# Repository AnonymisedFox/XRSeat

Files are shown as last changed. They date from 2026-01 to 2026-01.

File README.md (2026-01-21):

# XRSeat prototype 

This repository contains **all the parts, files, and components required for the fabrication and assembly of the XRSeat prototype**.
Every element has been included to ensure a complete understanding of the structure, the interactions between parts, and the overall system behavior.

## Introduction: what is XRSeat?
XRSeat is a system we built to facilitate the creation of multimodal experiences in Extended Reality (XR). 
It is a chair device providing lighting, spatialized audio, vibro-tactile feedback and wind sensations. We submitted a scientific paper to the IMX 2026 conference with more details about this research prototype.

Teaser_v2

To start, we suggest to have a look at the Technical_Drawings_Prototype pdf to have a global view of the chair and its components.
You then then have a look at the list of Required_Hardware, before digging into the design files in the CAD and Step_Files folder. 
Happy exploration!

## Content of this repo
The current repo, anonymised for the submission of the paper, contains:
* Mechanical and structural parts
* Assembly elements
* Design and reference files
* Prototype-specific components

Chaise_XR_v1b

## File Formats

All design files are **also provided in native SolidWorks format**, ensuring full parametric access, editability, and compatibility with SolidWorks-based workflows.

## Known issues
Currently, the POÄNG chair chair model is **not** provided in STEP format.
This results in:
* limited parametric editing,
* constraints when integrating the model into certain CAD software,
* the need for adaptation or conversion if structural modifications are required.

## Final note

Aside from this specific issue, **all other prototype elements are present and usable** in their current format.

---

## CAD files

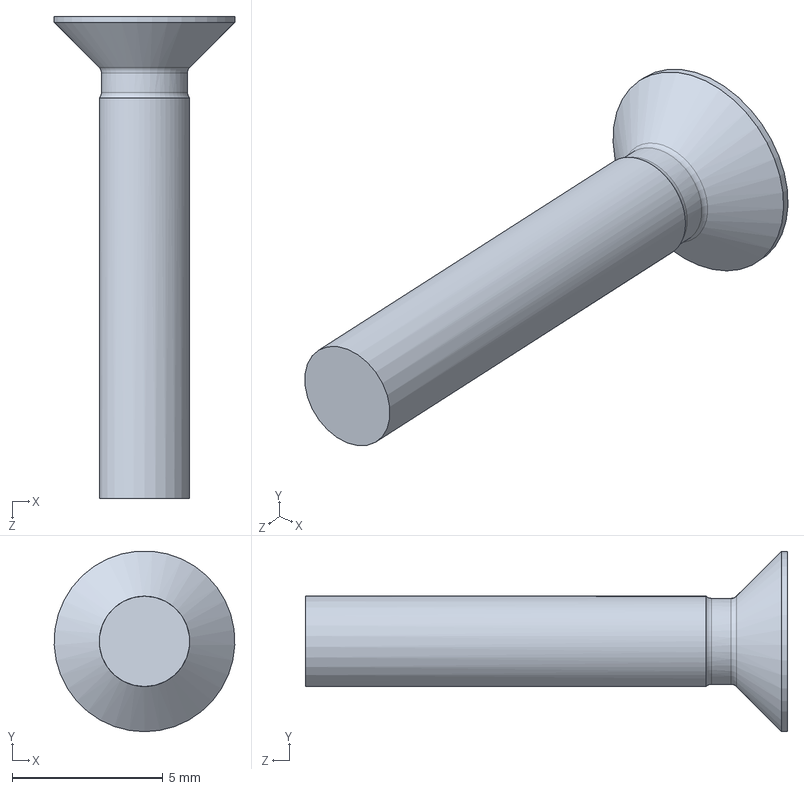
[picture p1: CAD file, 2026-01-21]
CAD/Solidworks/ARMSET_PART/vis_uni_5933_m3x16-a2_0.SLDPRT
5.99 x 5.99 x 16.0 mm

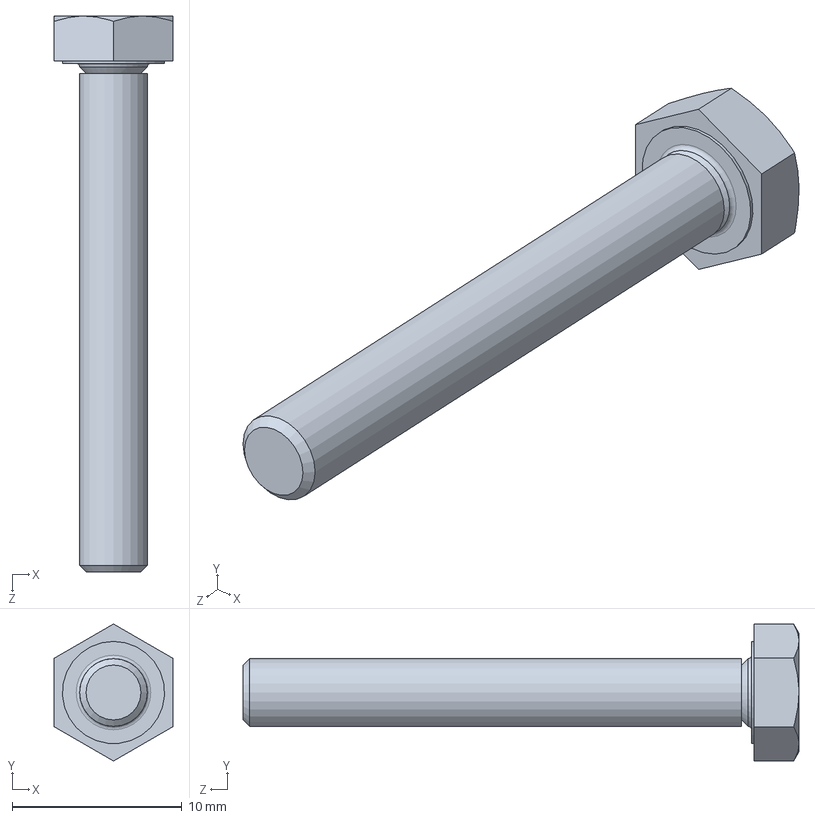
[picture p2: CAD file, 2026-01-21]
CAD/Solidworks/BACK_PART/din_en_24017_m4x30.SLDPRT
7.00 x 8.08 x 32.8 mm

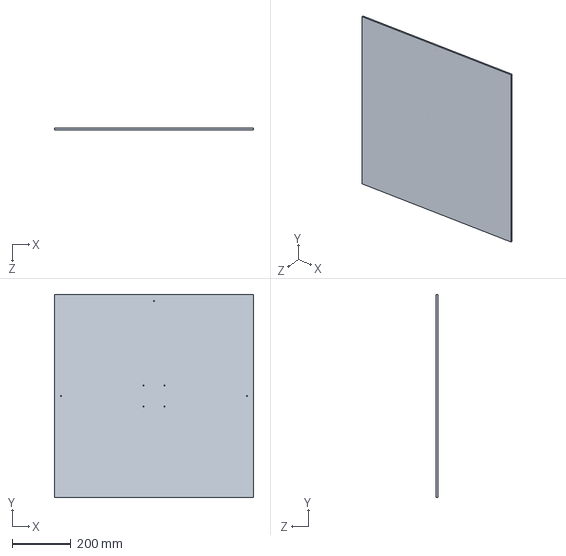
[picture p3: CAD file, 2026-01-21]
CAD/Solidworks/GROUND_PART/FOOT-PLATE.SLDPRT
680.0 x 694.0 x 6.00 mm

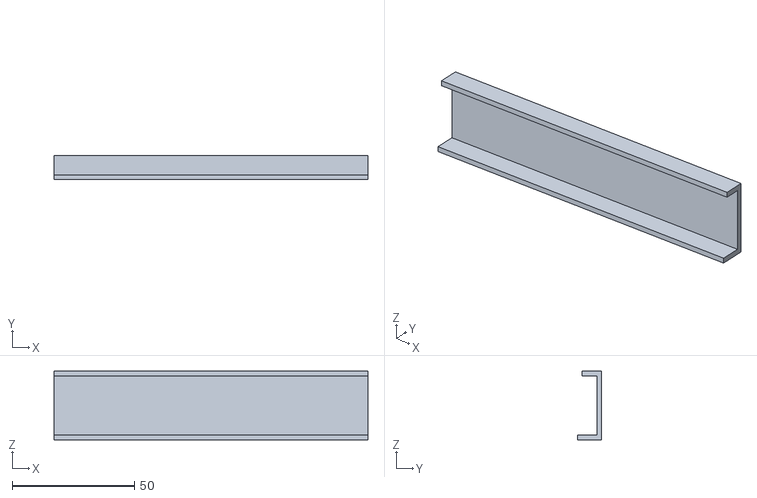
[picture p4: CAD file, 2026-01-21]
CAD/Solidworks/HEAD_PART/LEFT-EAR-Support_LED_P1.STL
128.2 x 10.0 x 28.0

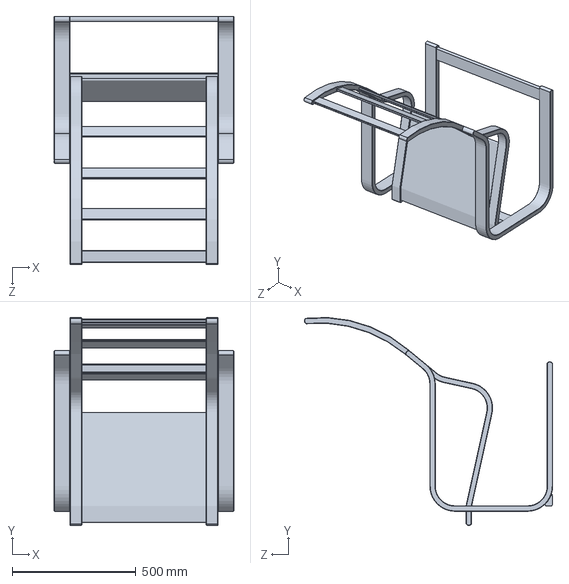
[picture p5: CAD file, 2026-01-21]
CAD/Solidworks/IKEA/POANG-CHAIR.SLDPRT
723.9 x 838.7 x 1001.3 mm

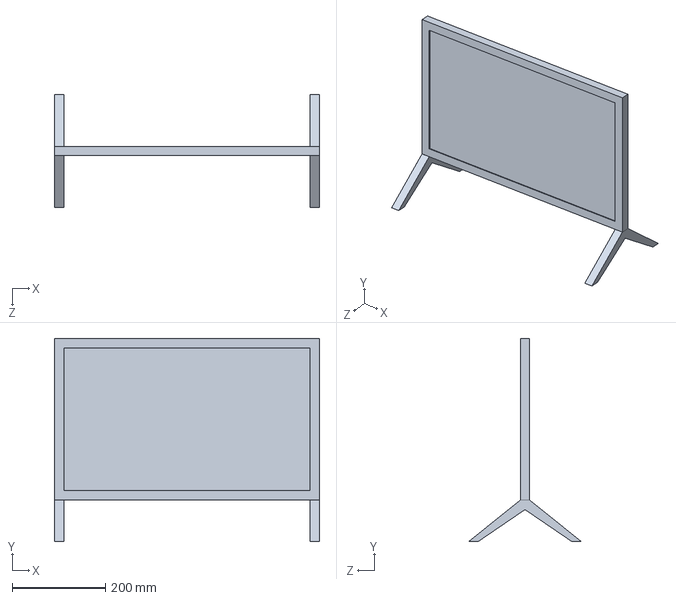
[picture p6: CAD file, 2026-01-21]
CAD/Solidworks/PROJECTION_PART/ILLUMETRY-SCREEN.SLDPRT
568.0 x 435.2 x 241.3 mm

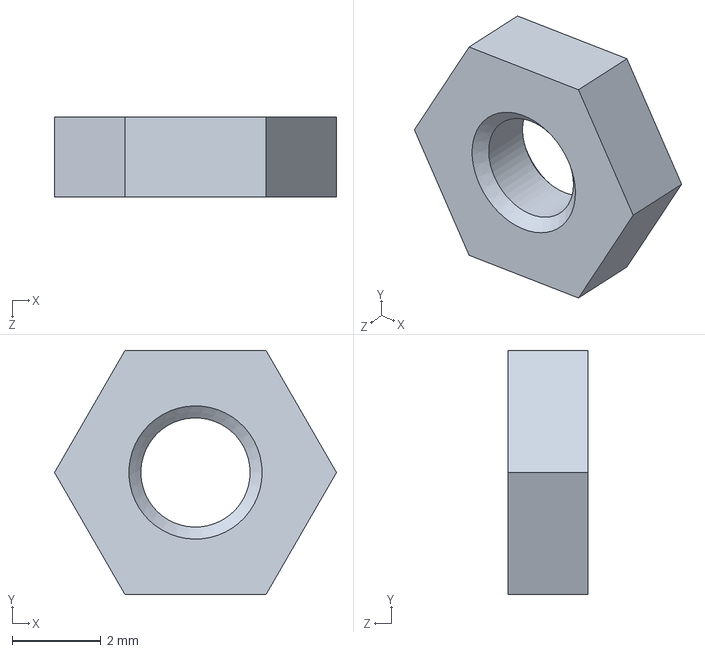
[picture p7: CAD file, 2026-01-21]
CAD/Step_Files/SubComponents/ecrou_iso_4036_m3.STEP
6.35 x 5.50 x 1.80 mm

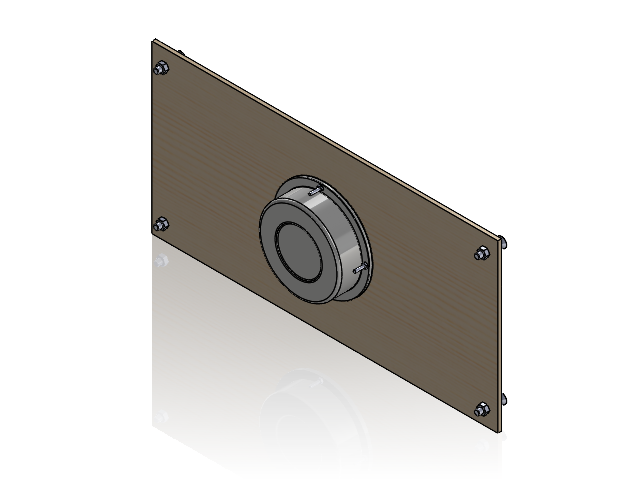
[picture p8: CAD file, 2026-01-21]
CAD/Solidworks/BACK_PART/BACK-PART.SLDASM
BACK-PLATE
BSX 130 WP metal body.stp
Dämpfung.stp
din_en_24017_m4x30 x 4
ecrou_din934_m4-6 x 4
ecrou_din934_m8-10 x 4
vis_uni_5933_m8x40-10_9_0 x 4

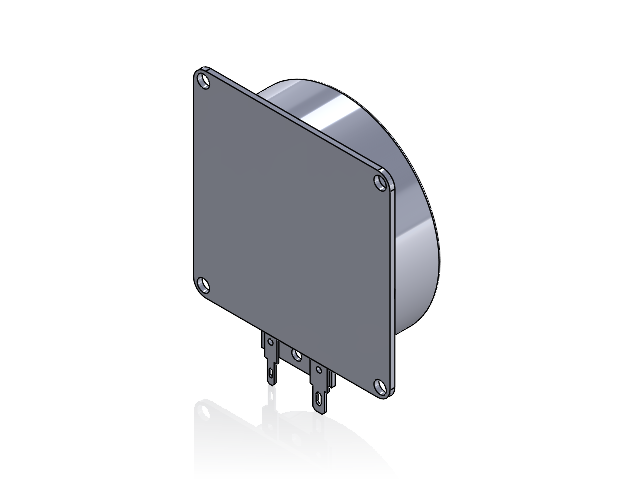
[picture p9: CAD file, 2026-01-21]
CAD/Solidworks/GROUND_PART/EX 80 S.SLDASM
Fiche_Visaton_EX_80_S
Visaton_EX_80_S

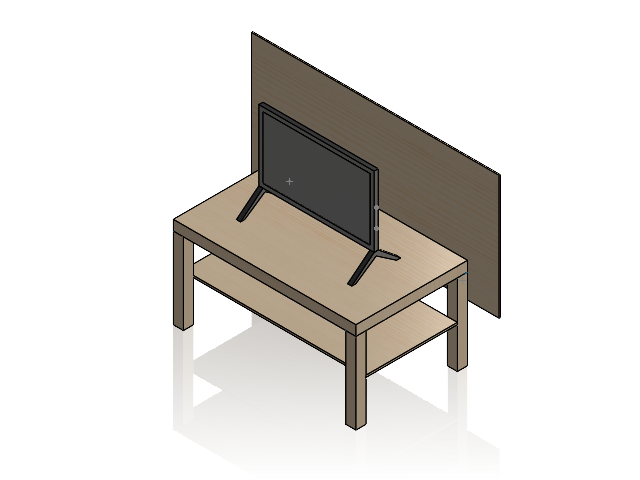
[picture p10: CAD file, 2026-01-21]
CAD/Solidworks/PROJECTION_PART/PROJECTION-PART.SLDASM
ILLUMETRY-SCREEN
LACK_TABLE
PROJECTION_BACK

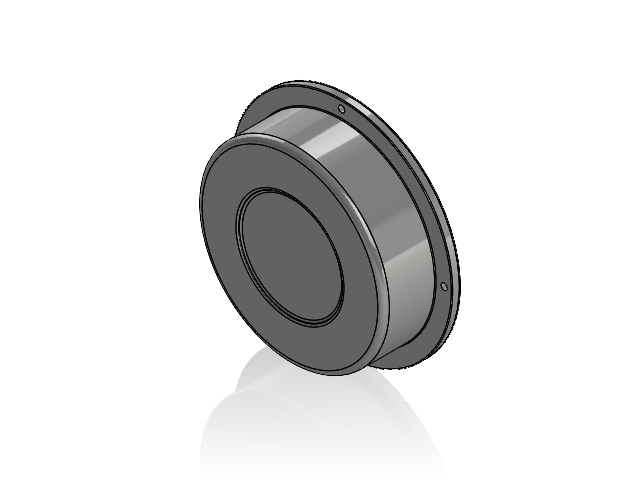
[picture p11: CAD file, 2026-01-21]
CAD/Solidworks/BACK_PART/VISATON BSX 130 WP 150908.SLDASM
BSX 130 WP metal body.stp
Dämpfung.stp

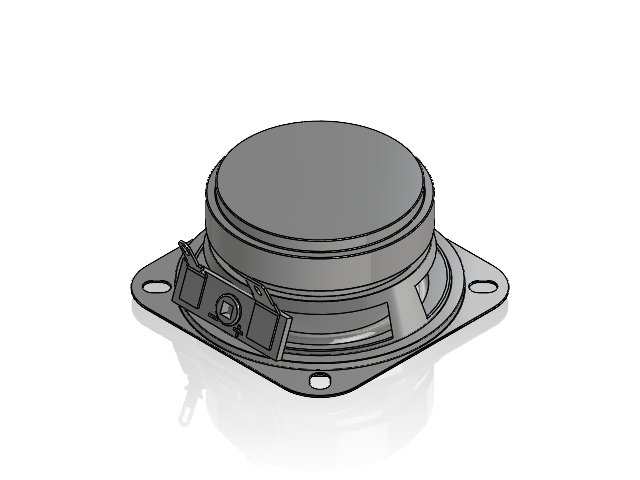
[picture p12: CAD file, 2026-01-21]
CAD/Solidworks/HEAD_PART/VISATON FR 58 170905.SLDASM
FR 58 Korb.stp
FR 58 Membran und Sicke.stp
FR 58 Gummidichtring.stp
FR 58 Magnet.stp
_Terminalplatte 29 x 9,2 x 1,6.stp
_Terminal 2.8-0.5 (135°) 2.stp
_Terminal 5.2-0.5 (135°).stp

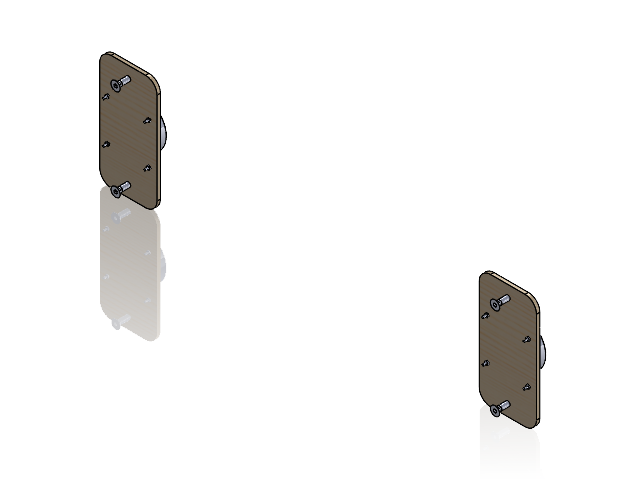
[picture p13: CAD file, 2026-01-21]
CAD/Solidworks/ARMSET_PART/ARMSET-PART.SLDASM
ARMSET-PLATE x 2
EX 80 S x 2
ecrou_iso_4036_m3 x 8
vis_uni_5933_m3x16-a2_0 x 8
ecrou_din934_m8-10 x 4
vis_uni_5933_m8x40-10_9_0 x 4

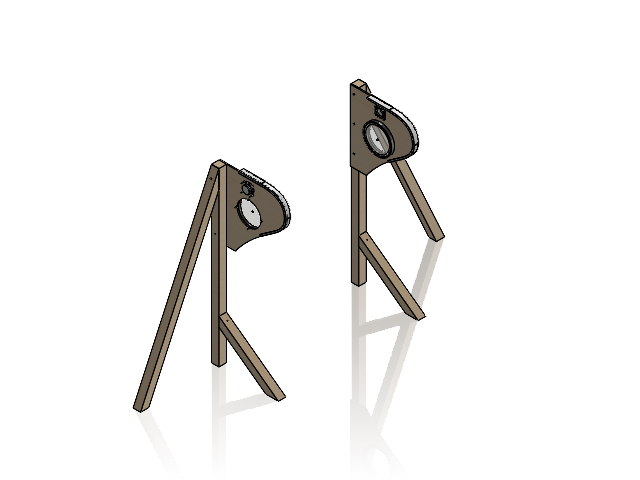
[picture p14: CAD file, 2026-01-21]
CAD/Solidworks/HEAD_PART/HEAD-PART.SLDASM
EAR x 2
WOODEN_BATTEN-1 x 2
WOODEN_BATTEN-2 x 2
WOODEN_BATTEN-3 x 2
screw_gb_t_951_3_5x40 x 10
Synjet_Plexi_TB x 2
Synjet_Support_TB x 2
FR 58 Korb.stp x 2
FR 58 Membran und Sicke.stp x 2
FR 58 Gummidichtring.stp x 2
FR 58 Magnet.stp x 2
_Terminalplatte 29 x 9,2 x 1,6.stp x 2
_Terminal 2.8-0.5 (135°) 2.stp x 2
_Terminal 5.2-0.5 (135°).stp x 2
ecrou_iso_4036_m3 x 16
vis_iso_4017-m3x30-10_9 x 16
EAR-Support_LED_P1 x 2
EAR-Support_LED_P2 x 2

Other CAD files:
CAD/Step_Files/MainStepFile.STEP
CAD/Step_Files/SubComponents/SCENT_ASSEMBLY.STEP
CAD/Step_Files/SubComponents/ARM_WOOD_ASSEMBLY.STEP
CAD/Solidworks/260120-PROTYPE.SLDASM
CAD/Solidworks/ARMSET_PART/ARMSET-PLATE.SLDPRT
CAD/Solidworks/ARMSET_PART/EX 80 S.SLDPRT
CAD/Solidworks/ARMSET_PART/ecrou_din934_m8-10.SLDPRT
CAD/Solidworks/ARMSET_PART/ecrou_iso_4036_m3.SLDPRT
CAD/Solidworks/ARMSET_PART/vis_uni_5933_m8x40-10_9_0.SLDPRT
CAD/Solidworks/BACK_PART/BACK-PLATE.SLDPRT
CAD/Solidworks/BACK_PART/ecrou_din934_m4-6.SLDPRT
CAD/Solidworks/BACK_PART/ecrou_din934_m8-10.SLDPRT
CAD/Solidworks/BACK_PART/vis_uni_5933_m8x40-10_9_0.SLDPRT
CAD/Solidworks/GROUND.SLDPRT
CAD/Solidworks/GROUND_PART/EX 80 S.SLDPRT
CAD/Solidworks/GROUND_PART/Fiche_Visaton_EX_80_S.SLDPRT
CAD/Solidworks/GROUND_PART/Visaton_EX_80_S.SLDPRT
CAD/Solidworks/GROUND_PART/WOODEN_BATTEN-44X44_L271.SLDPRT
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

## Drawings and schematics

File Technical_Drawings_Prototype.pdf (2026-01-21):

sauf indications contraires, unités en mm

NOM | SIGNATURE | DATE | REFERENCE: PROTYPE 13/03/2025

AUTEUR

VERIF. | | | | | ECHELLE:1:20
PROPRIETARY AND CONFIDENTIAL THE INFORMATION CONTAINED IN THIS DRAWING IS THE SOLE PROPERTY OF IMMERSION SAS. ANY REPRODUCTION IN PART OR AS A WHOLE WITHOUT THE WRITTEN PERMISSION OF IMMERSION SAS IS PROHIBITED. | | VERSION: 1.0

NE PAS CHANGER
L'ECHELLE

PAR: | LE:

sauf indications contraires, unités en mm

NOM | SIGNATURE | DATE | REFERENCE: ARMSET-PART 13/03/2025

AUTEUR

VERIF. | | | | | ECHELLE:1:5

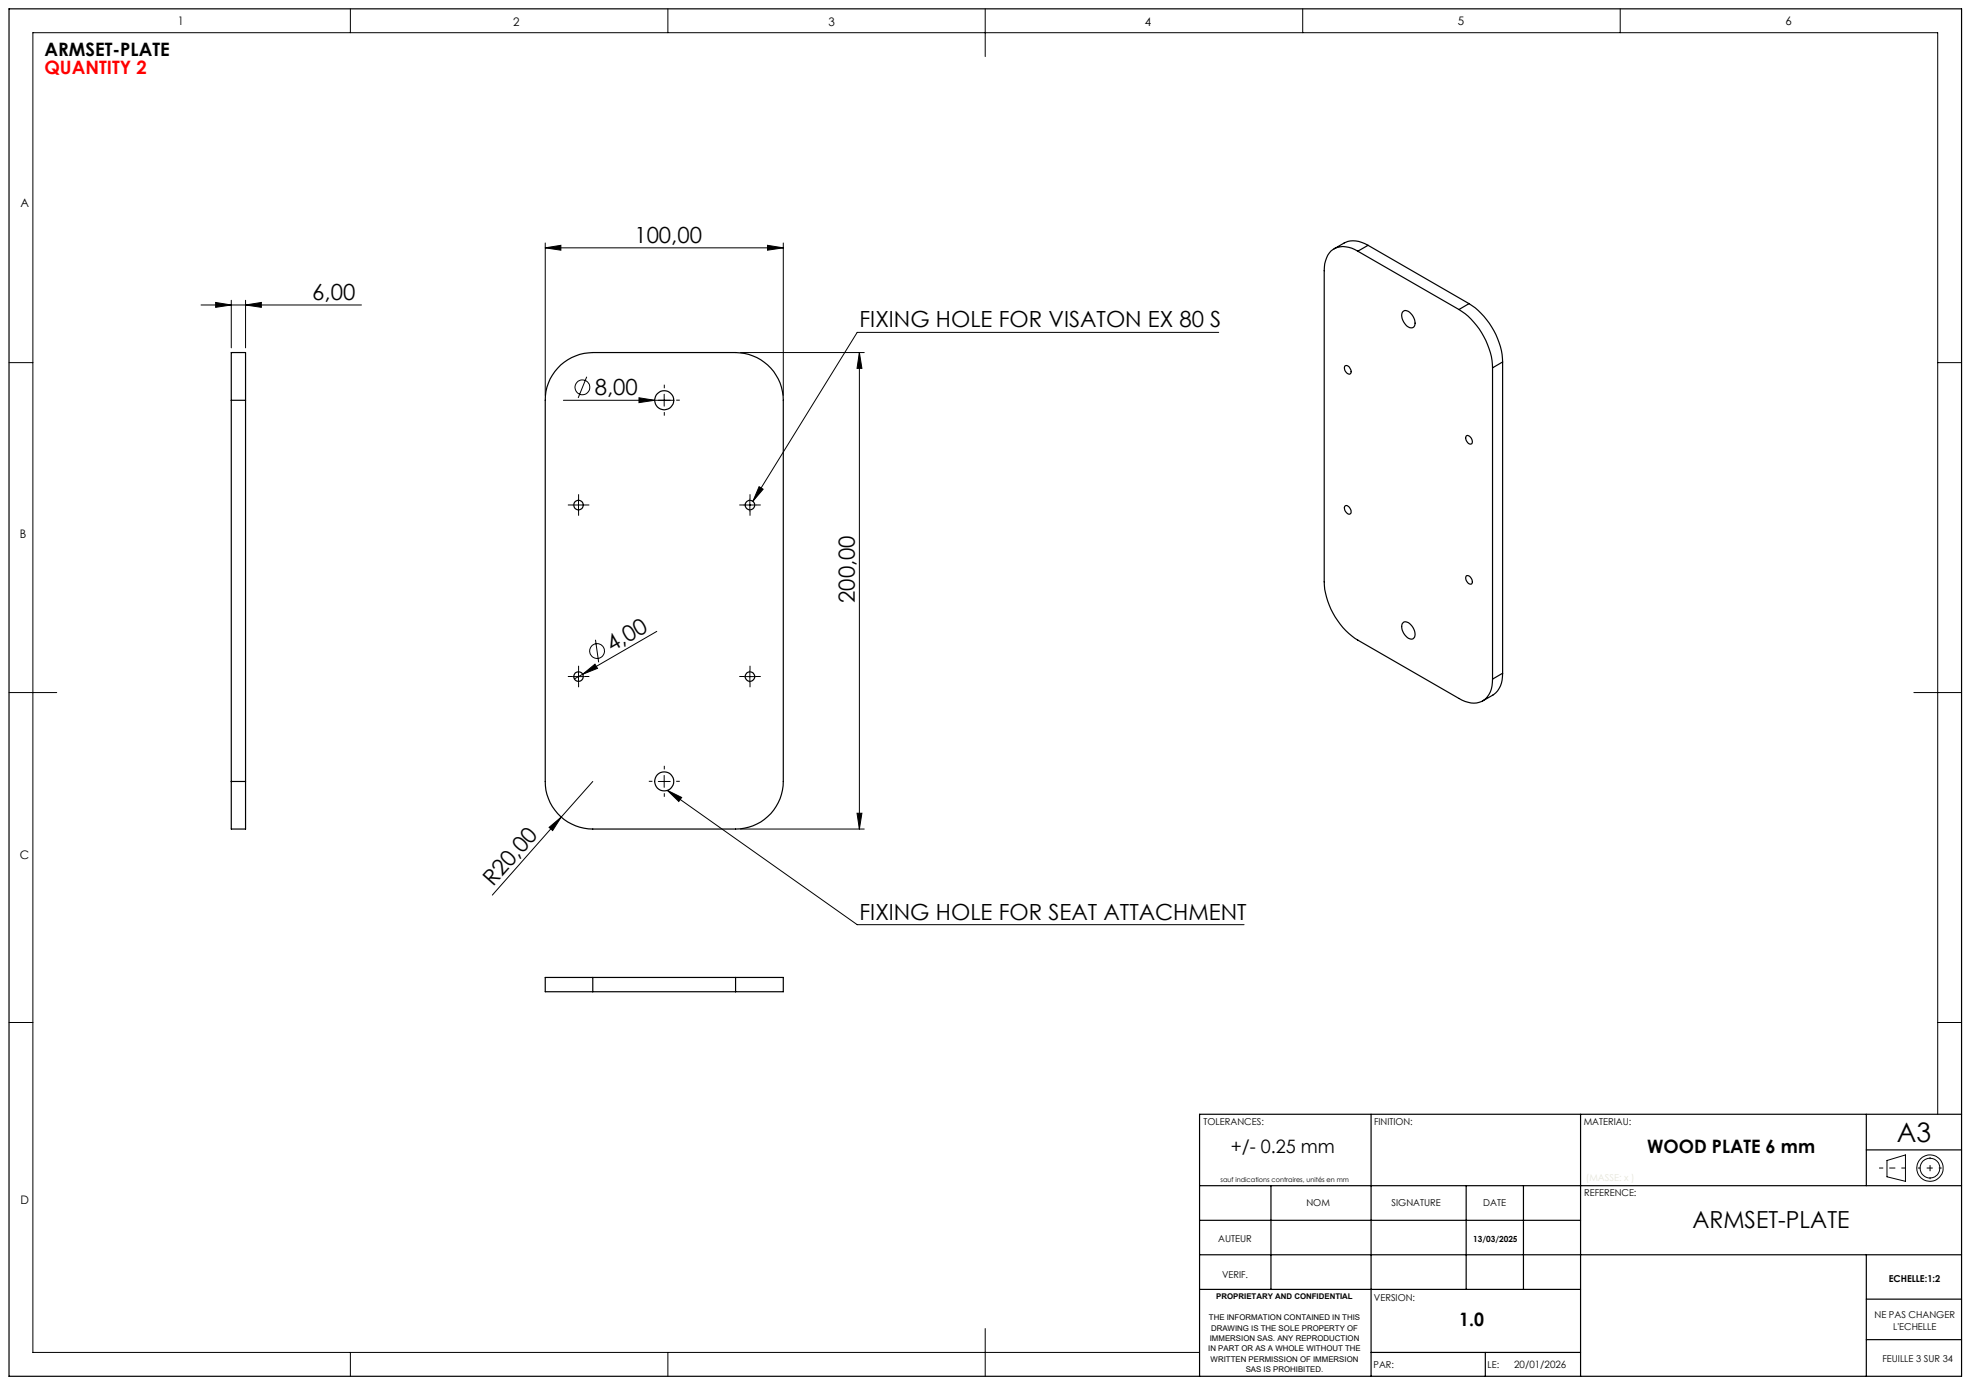
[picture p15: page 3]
WOOD PLATE 6 mm; FEUILLE 3 SUR 34; QUANTITY 2; (MASSE: x )

FIXING HOLE FOR VISATON EX 80 S

FIXING HOLE FOR SEAT ATTACHMENT

sauf indications contraires, unités en mm

NOM | SIGNATURE | DATE | REFERENCE: ARMSET-PLATE 13/03/2025

AUTEUR

VERIF. | | | | | ECHELLE:1:2

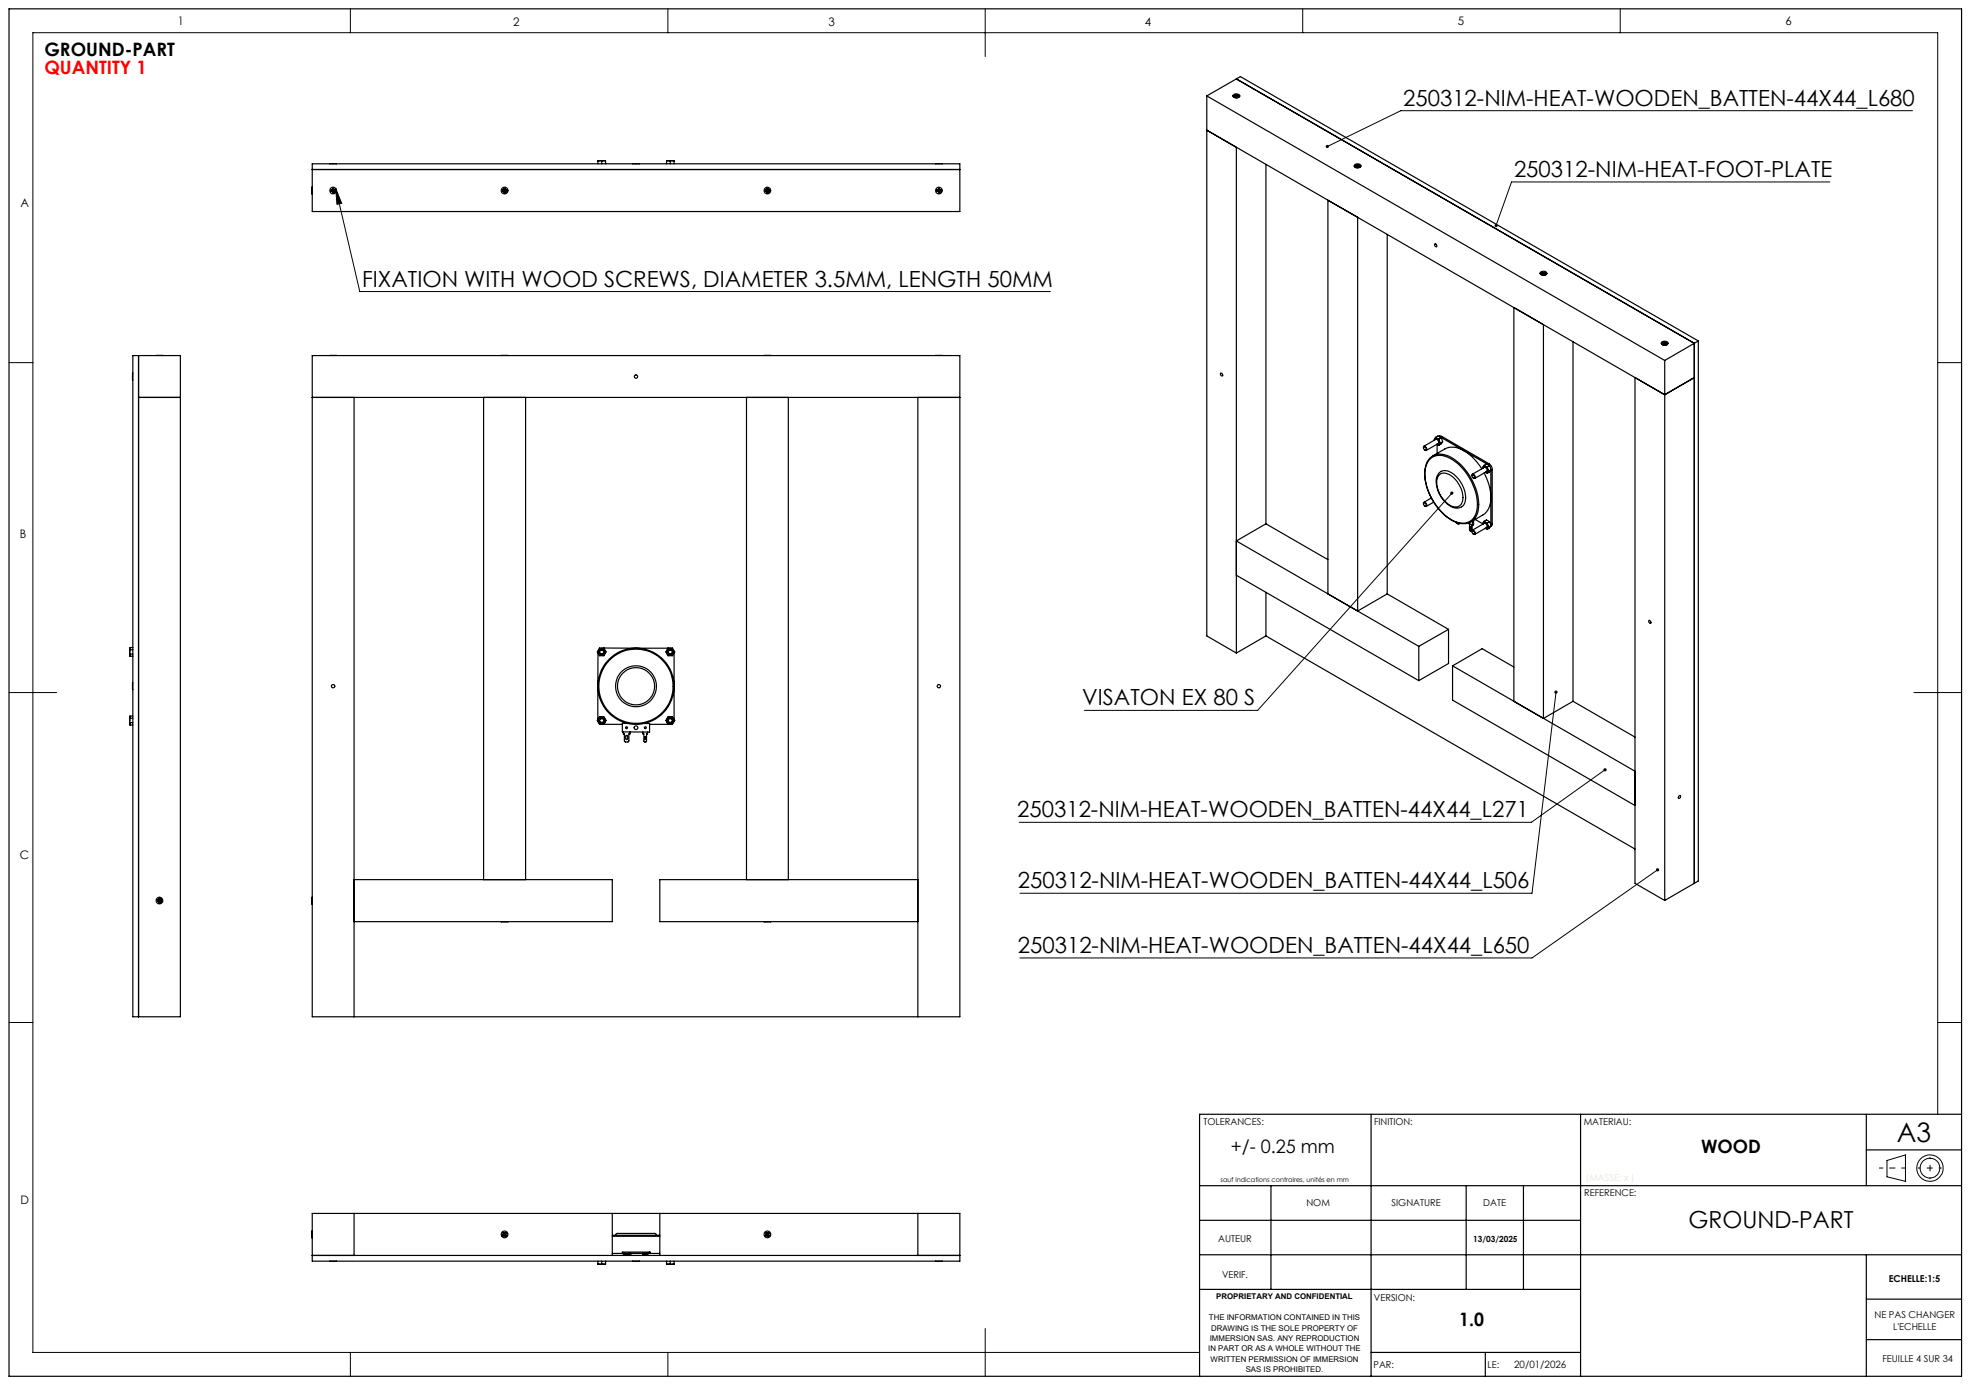
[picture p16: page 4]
VISATON EX 80 S; FEUILLE 4 SUR 34; (MASSE: x )

250312-NIM-HEAT-FOOT-PLATE

FIXATION WITH WOOD SCREWS, DIAMETER 3.5MM, LENGTH 50MM

sauf indications contraires, unités en mm

NOM | SIGNATURE | DATE | REFERENCE: GROUND-PART 13/03/2025

AUTEUR

VERIF. | | | | | ECHELLE:1:5

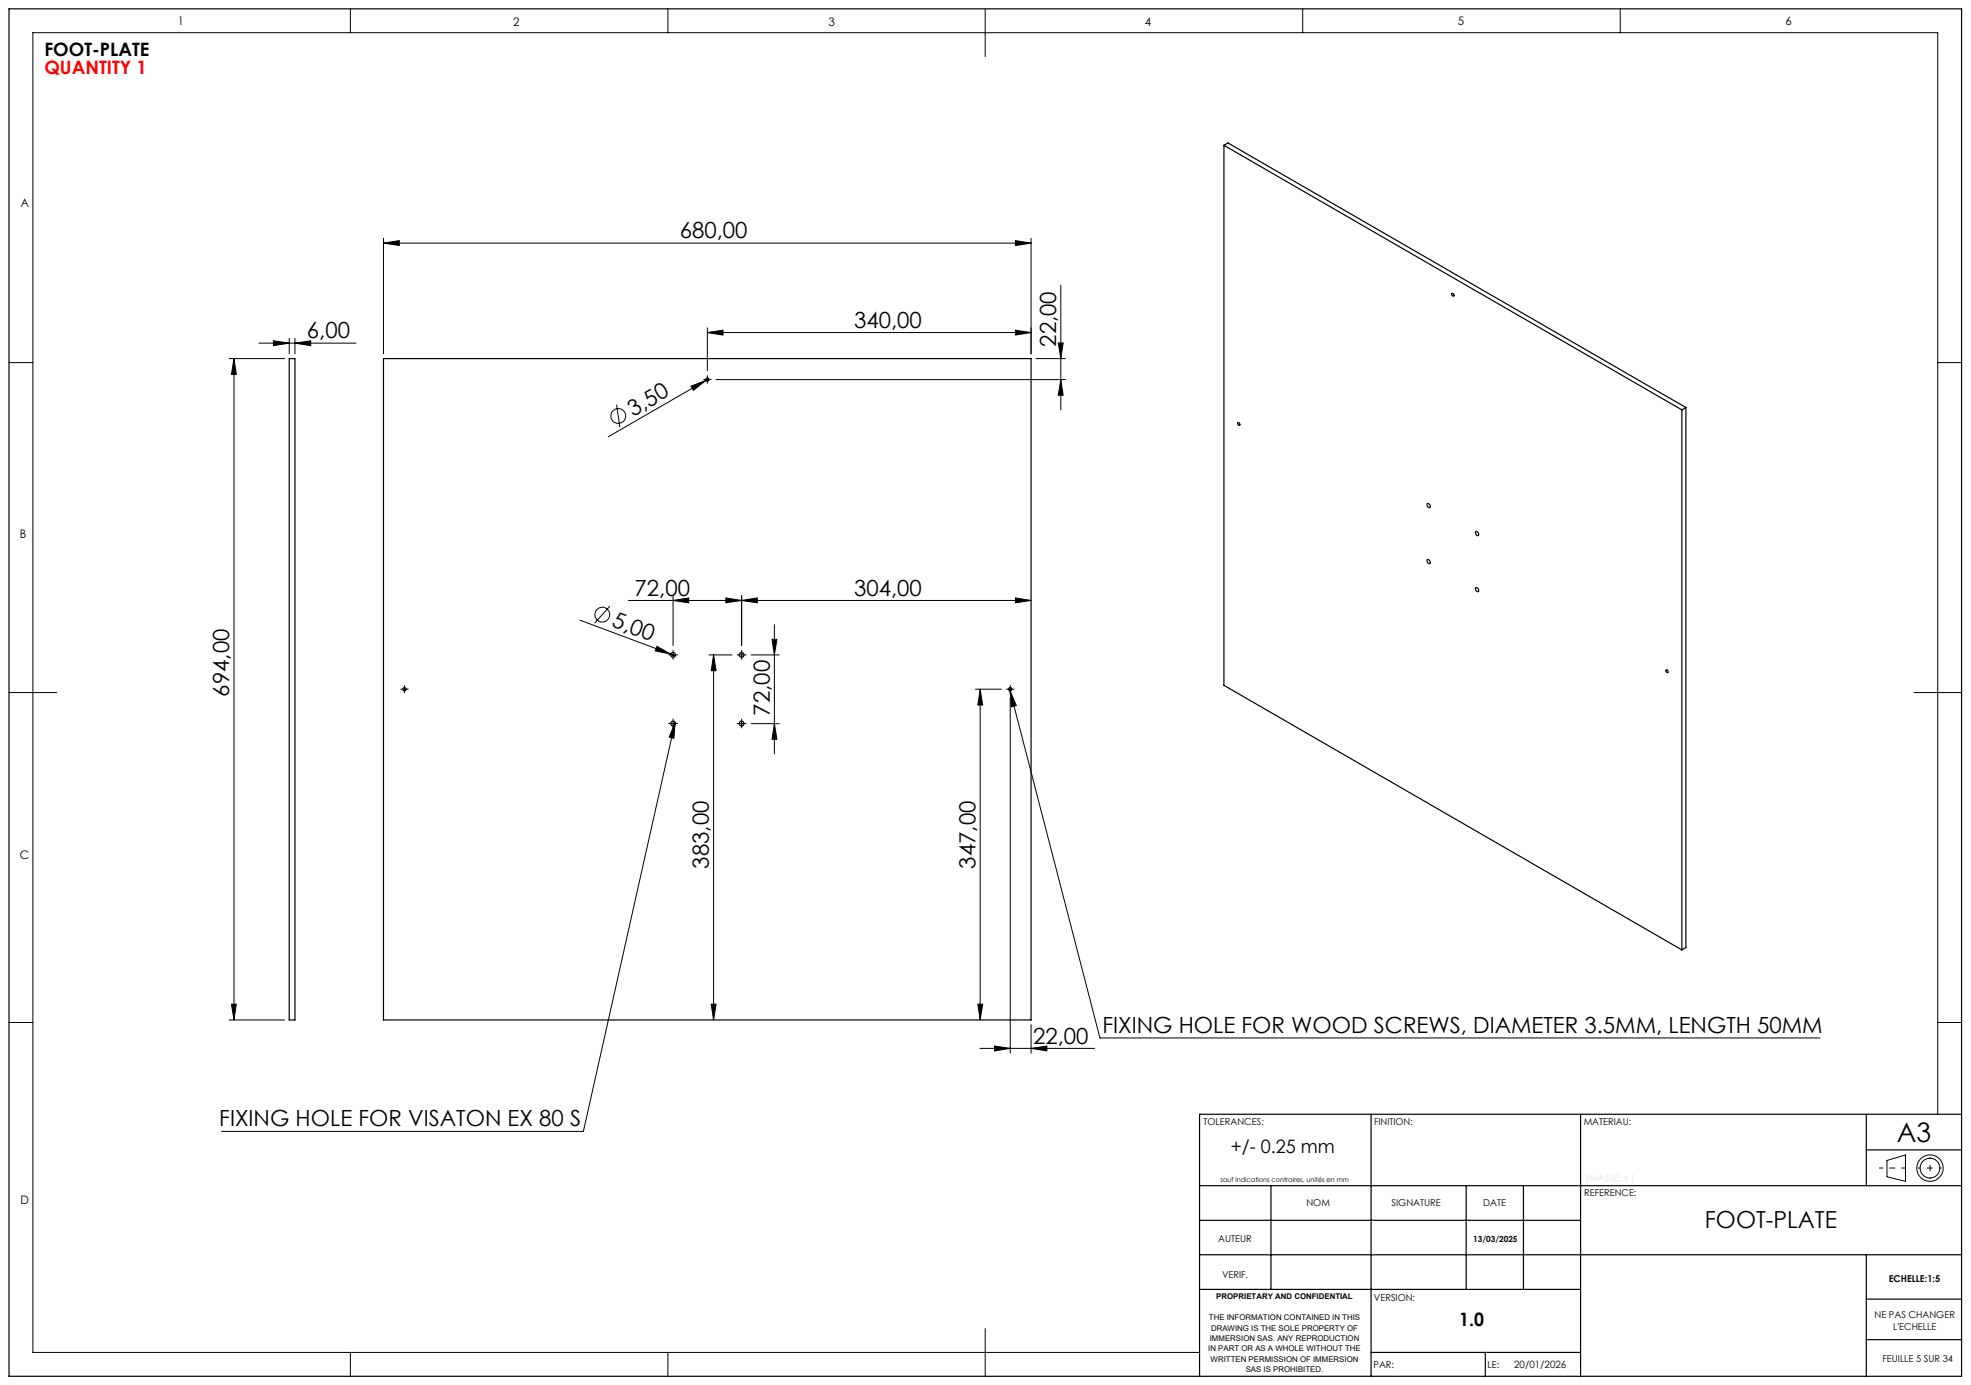
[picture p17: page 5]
FEUILLE 5 SUR 34; (MASSE: x )

FIXING HOLE FOR VISATON EX 80 S 694,00

FIXING HOLE FOR WOOD SCREWS, DIAMETER 3.5MM, LENGTH 50MM

sauf indications contraires, unités en mm

NOM | SIGNATURE | DATE | REFERENCE: FOOT-PLATE

AUTEUR | | | 13/03/2025

VERIF. | | | | | ECHELLE:1:5

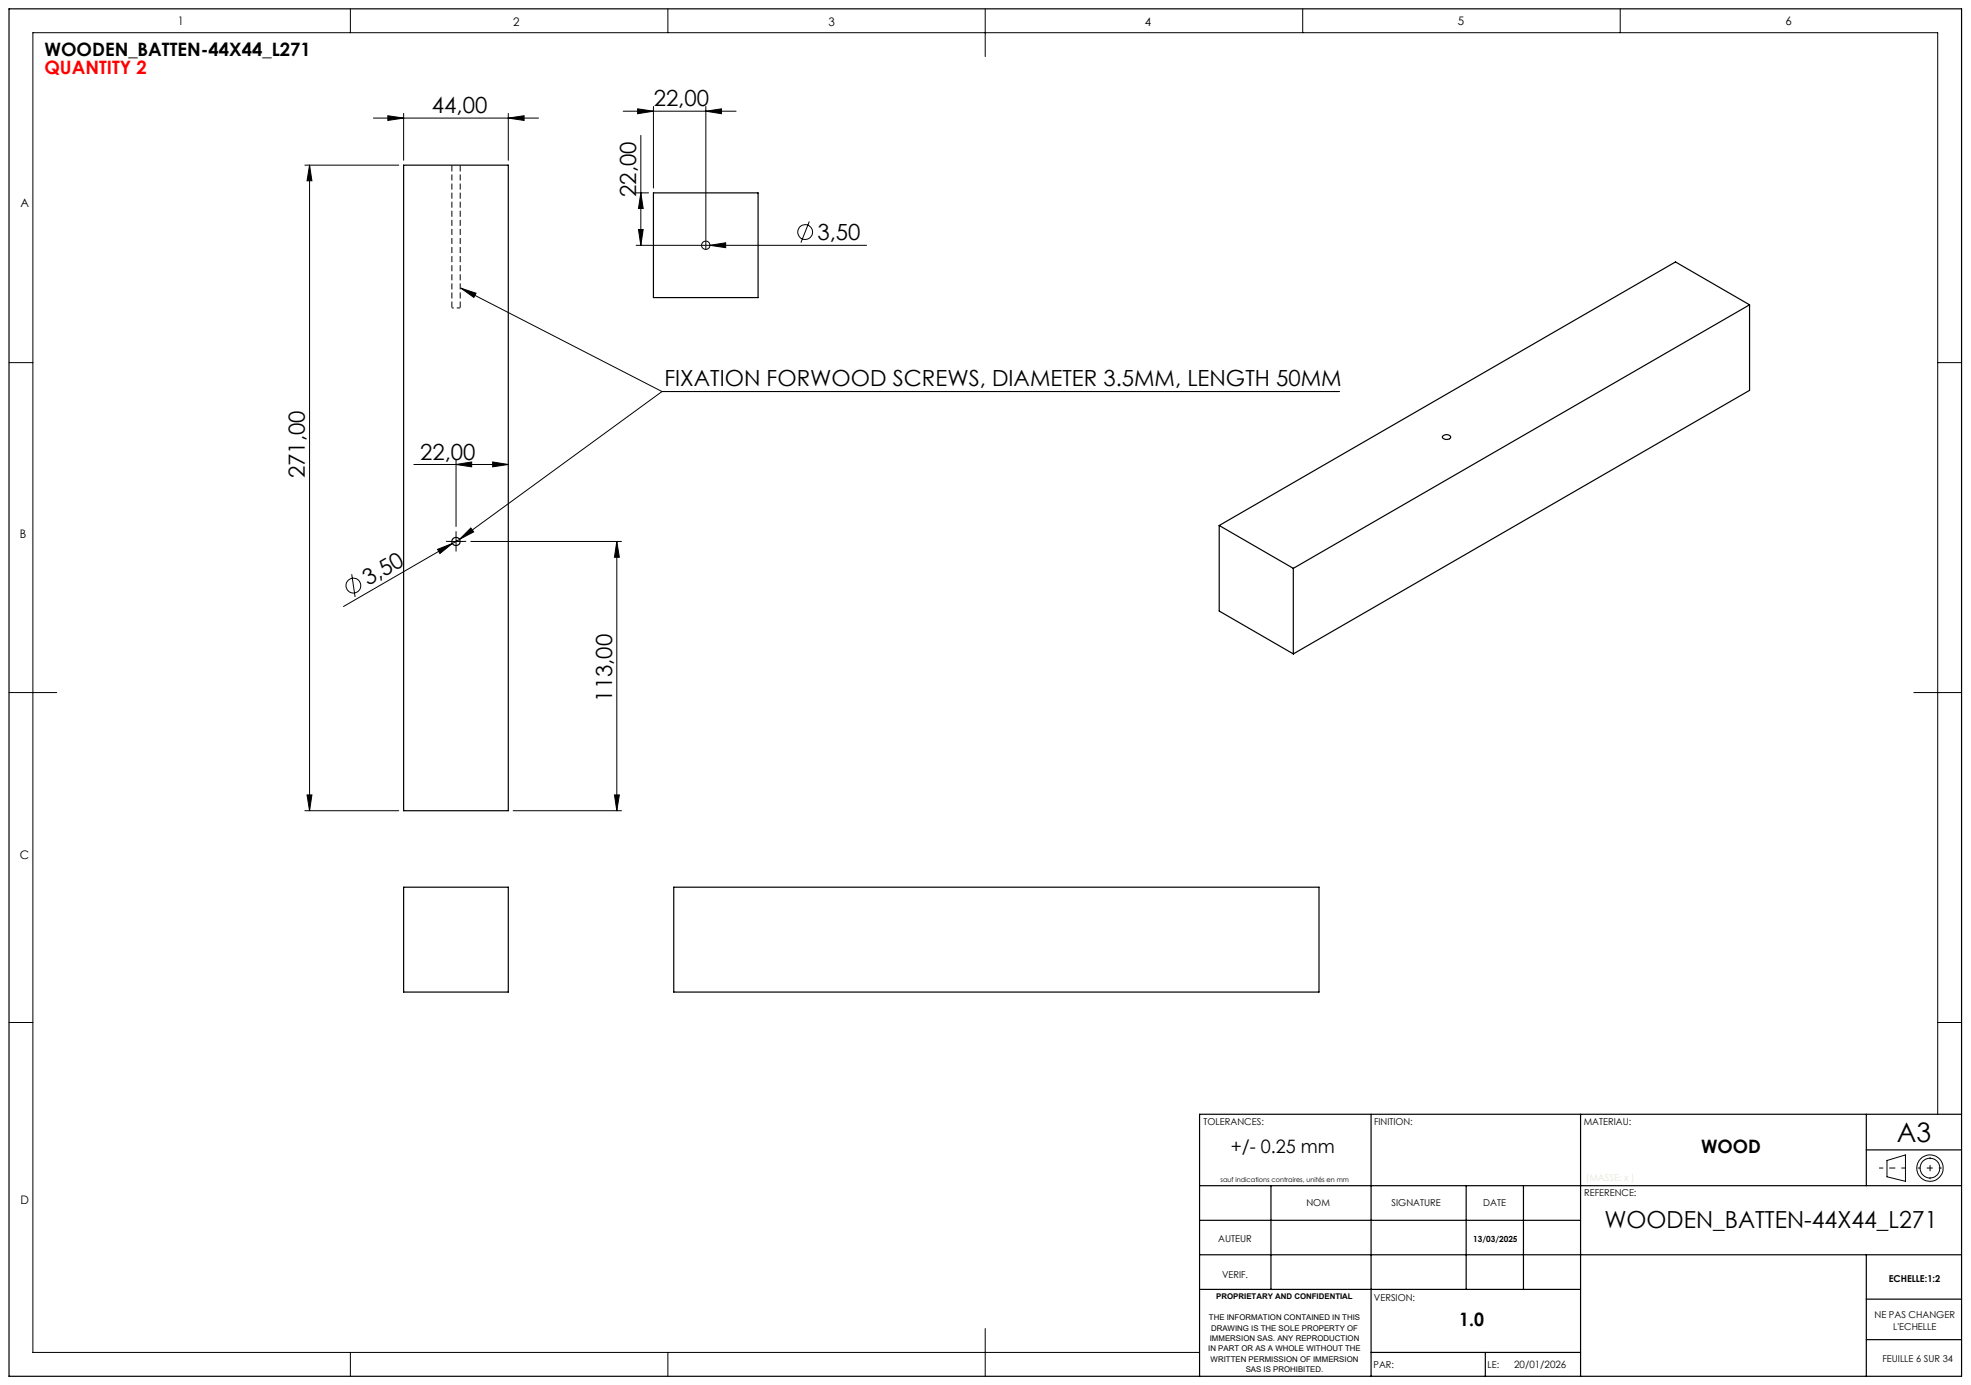
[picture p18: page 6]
FEUILLE 6 SUR 34; (MASSE: x )

FIXATION FORWOOD SCREWS, DIAMETER 3.5MM, LENGTH 50MM

sauf indications contraires, unités en mm

NOM | SIGNATURE | DATE | REFERENCE: WOODEN_BATTEN-44X44_L271 13/03/2025

AUTEUR

VERIF. | | | | | ECHELLE:1:2

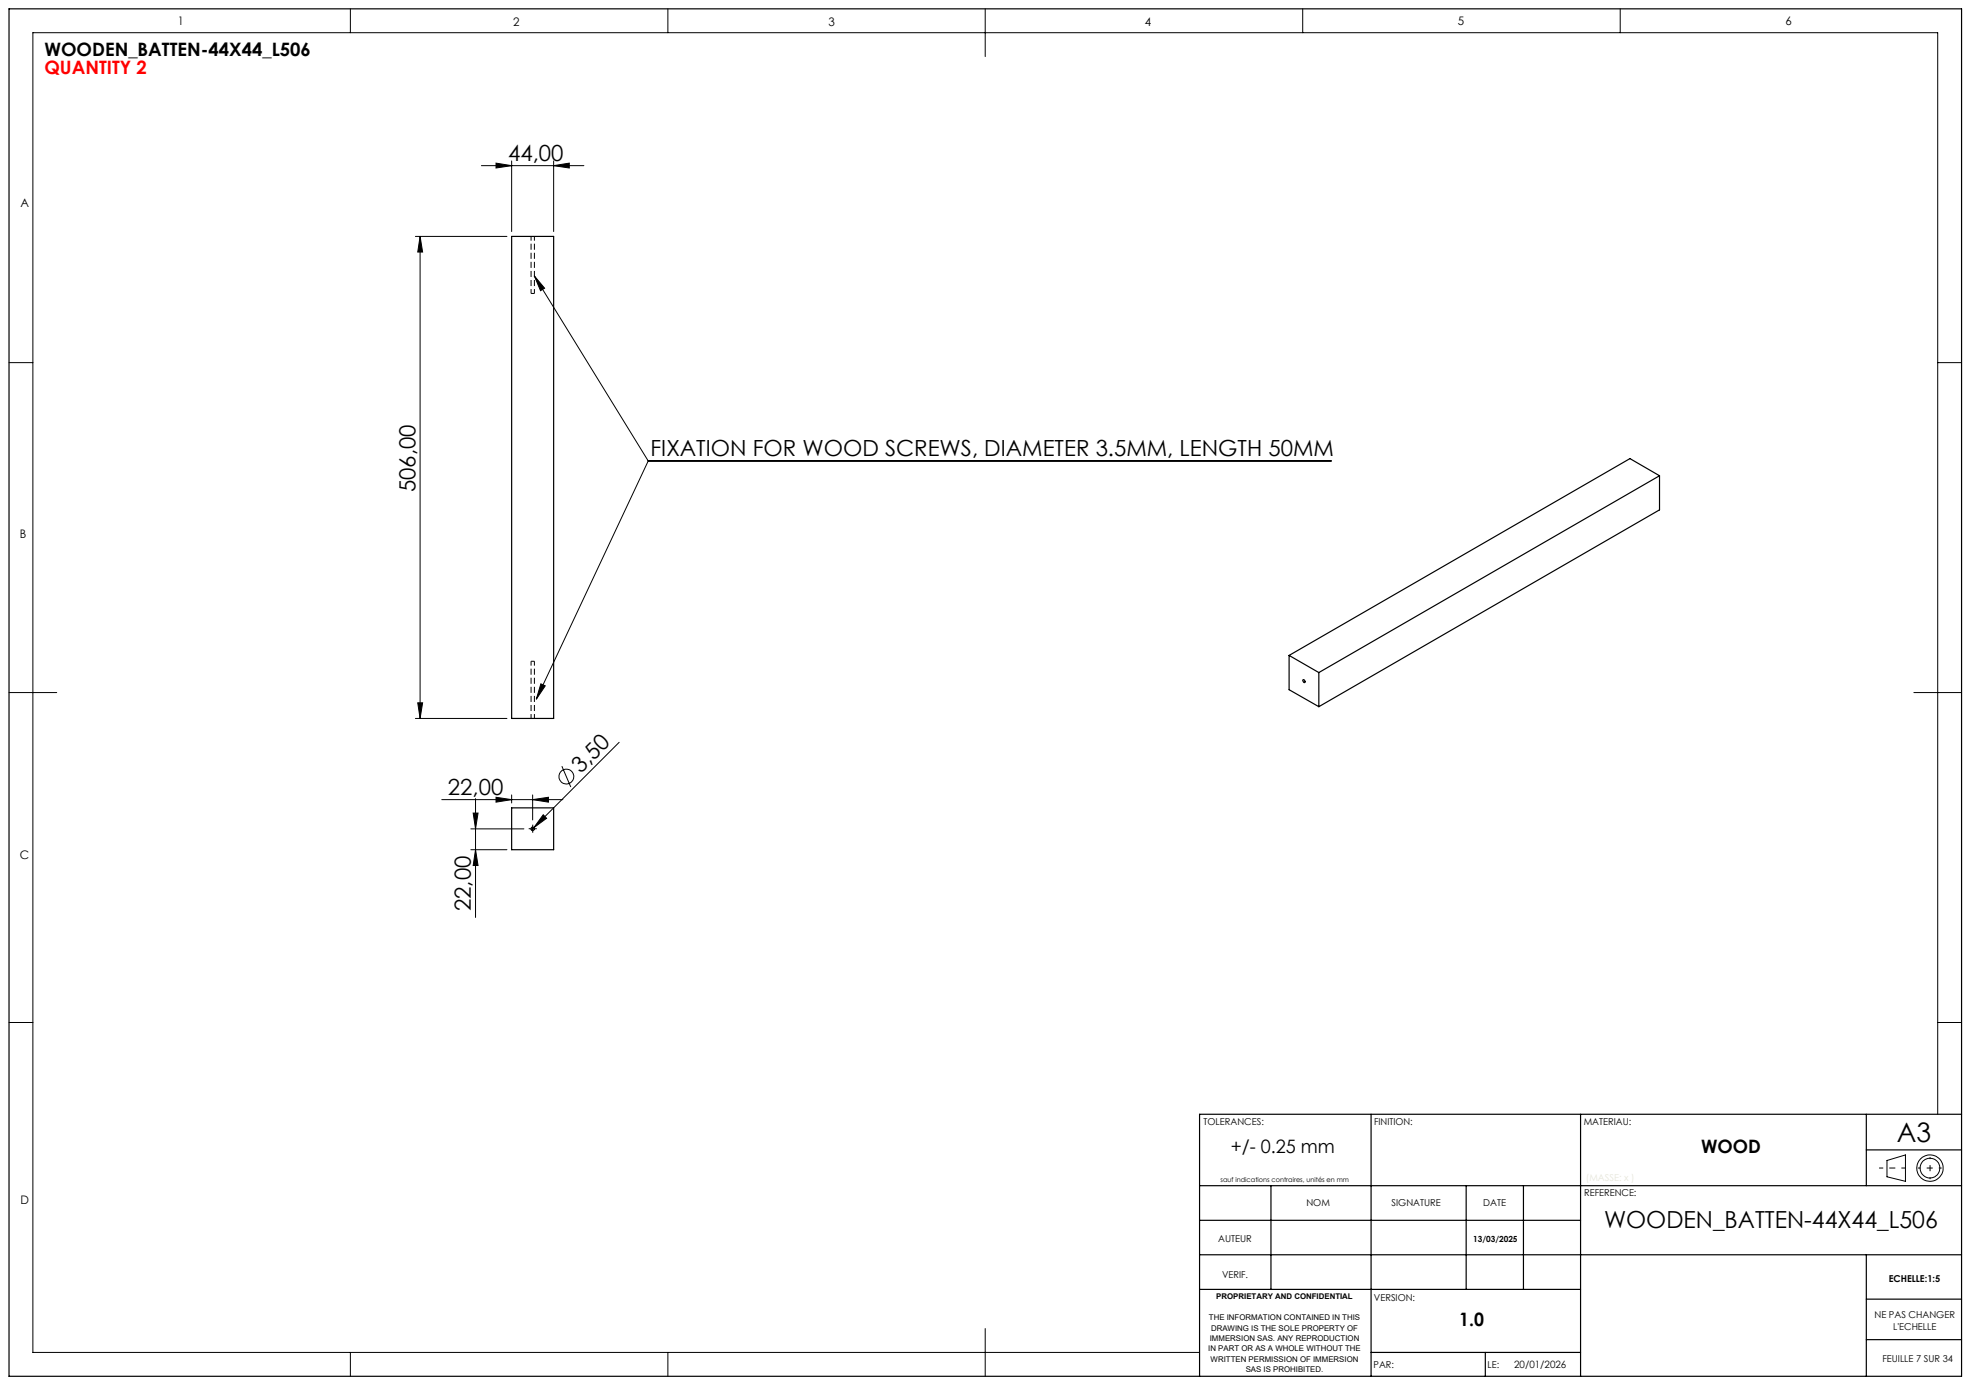
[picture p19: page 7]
FEUILLE 7 SUR 34; (MASSE: x )

FIXATION FOR WOOD SCREWS, DIAMETER 3.5MM, LENGTH 50MM

sauf indications contraires, unités en mm

NOM | SIGNATURE | DATE | REFERENCE: WOODEN_BATTEN-44X44_L506 13/03/2025

AUTEUR

VERIF. | | | | | ECHELLE:1:5

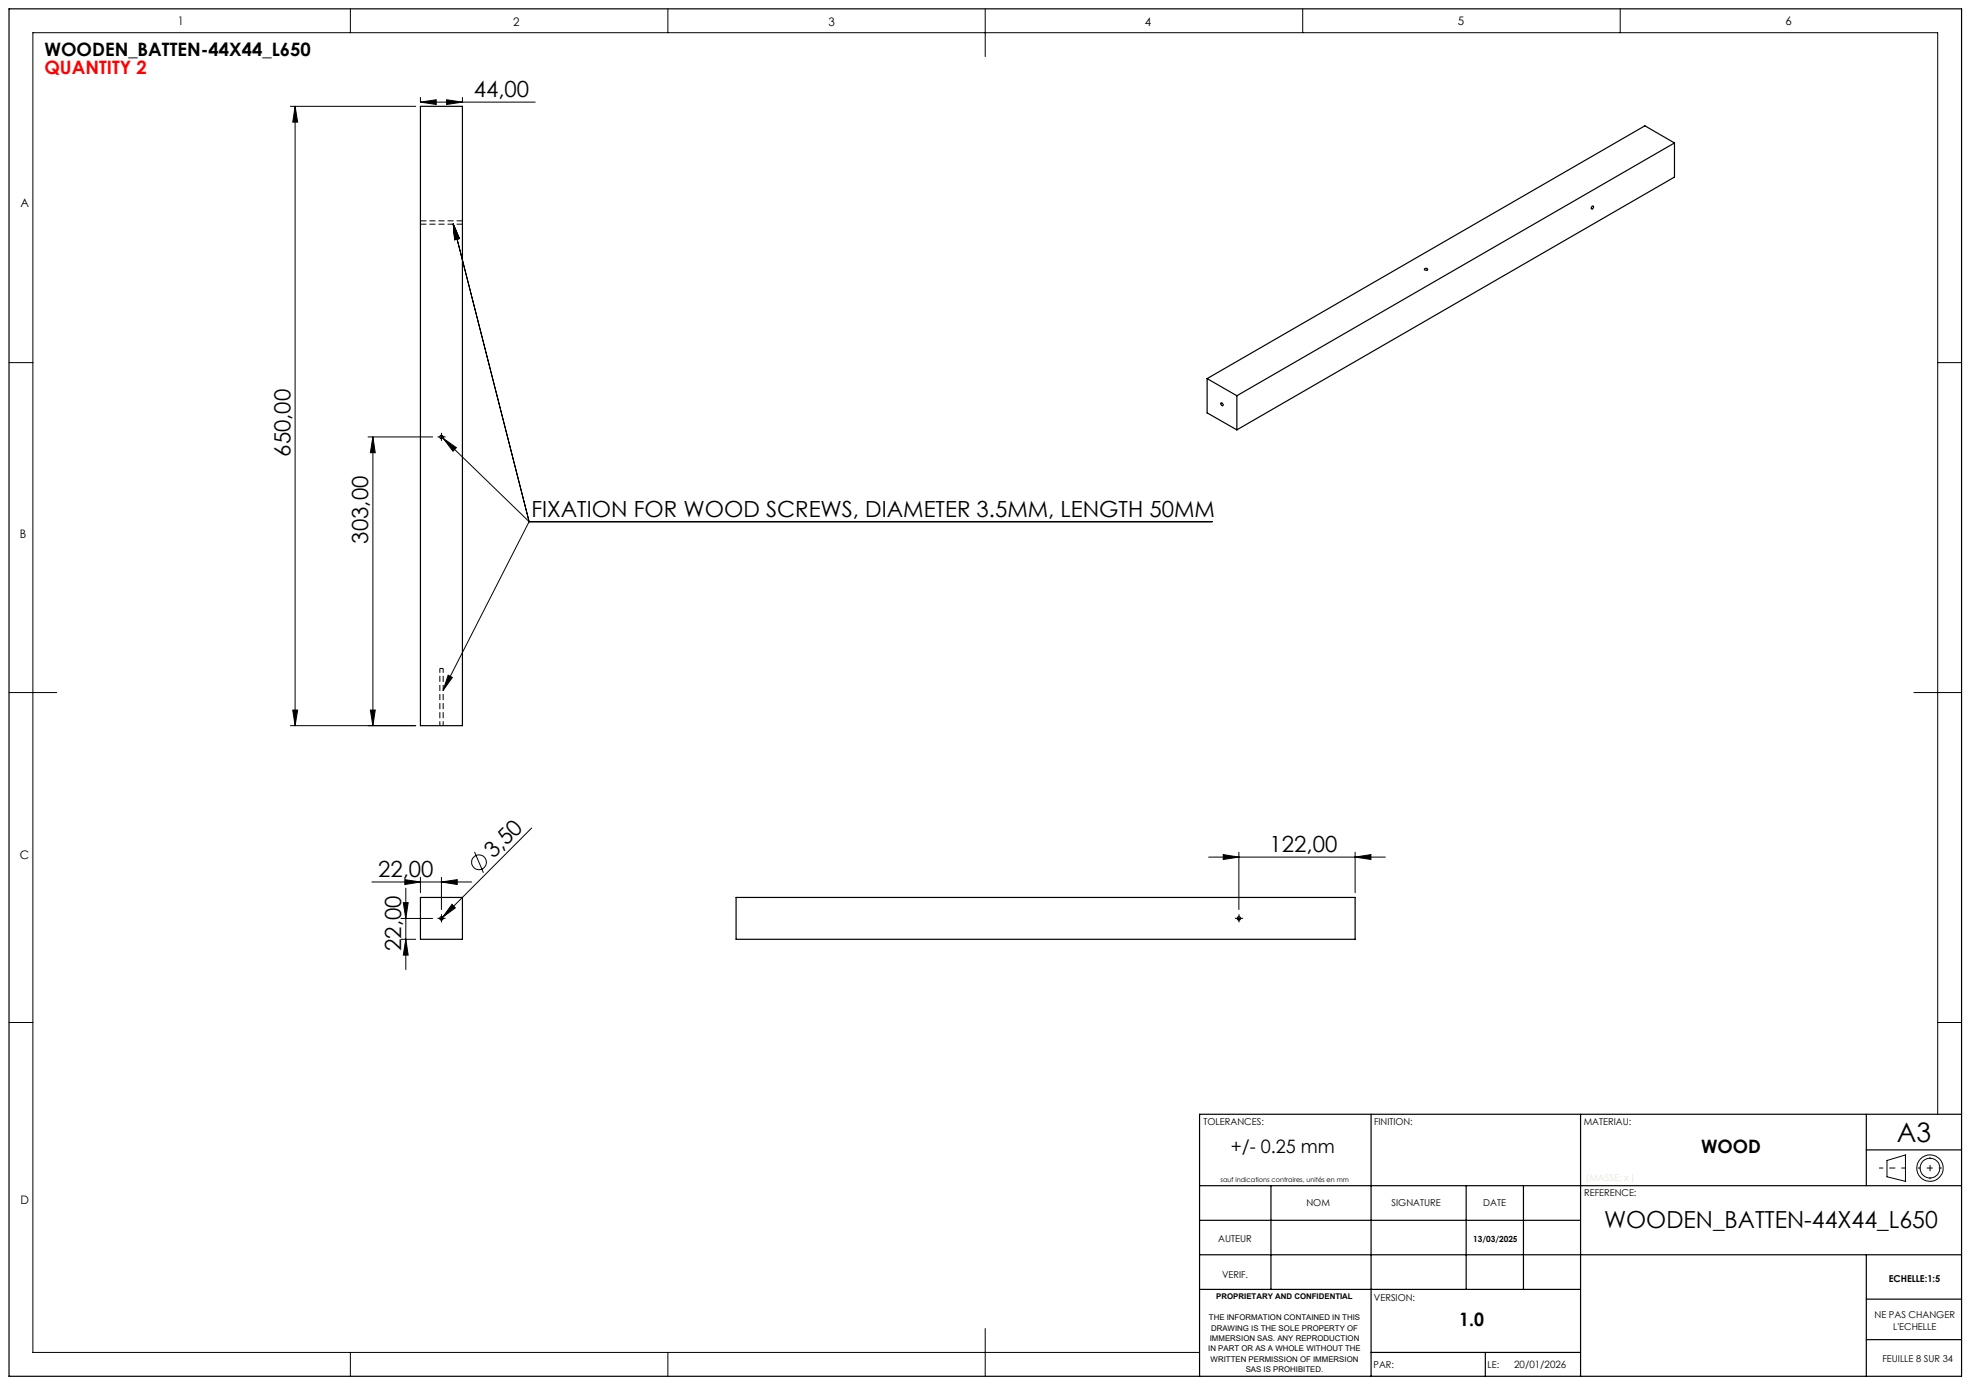
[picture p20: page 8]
FEUILLE 8 SUR 34; (MASSE: x )

FIXATION FOR WOOD SCREWS, DIAMETER 3.5MM, LENGTH 50MM

sauf indications contraires, unités en mm

NOM | SIGNATURE | DATE | REFERENCE: WOODEN_BATTEN-44X44_L650 13/03/2025

AUTEUR

VERIF. | | | | | ECHELLE:1:5

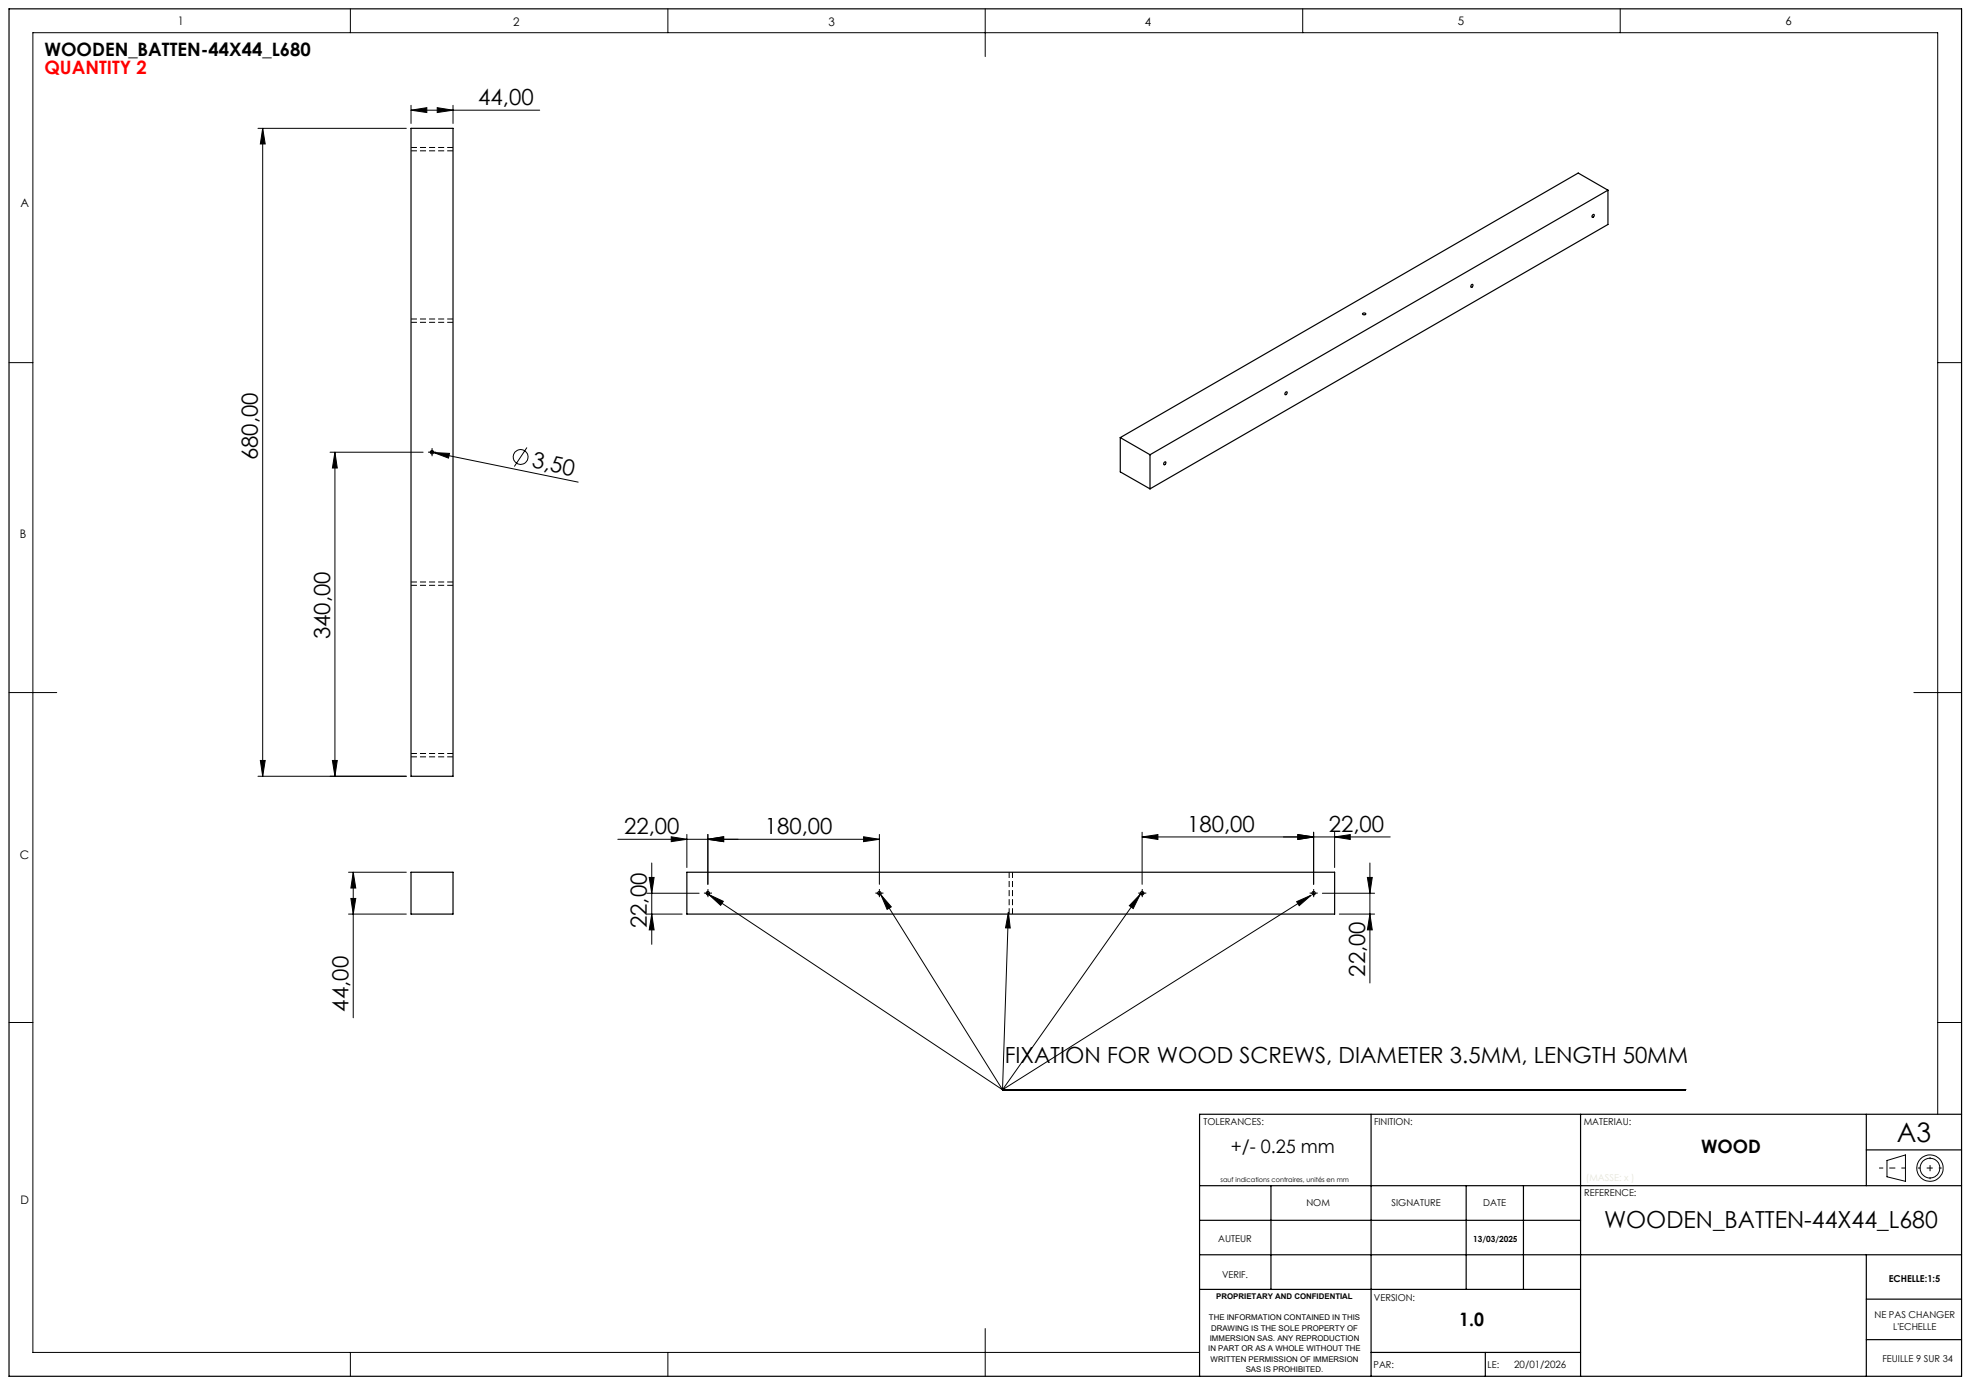
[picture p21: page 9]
FEUILLE 9 SUR 34; (MASSE: x )

FIXATION FOR WOOD SCREWS, DIAMETER 3.5MM, LENGTH 50MM

sauf indications contraires, unités en mm

NOM | SIGNATURE | DATE | REFERENCE: WOODEN_BATTEN-44X44_L680 13/03/2025

AUTEUR

VERIF. | | | | | ECHELLE:1:5

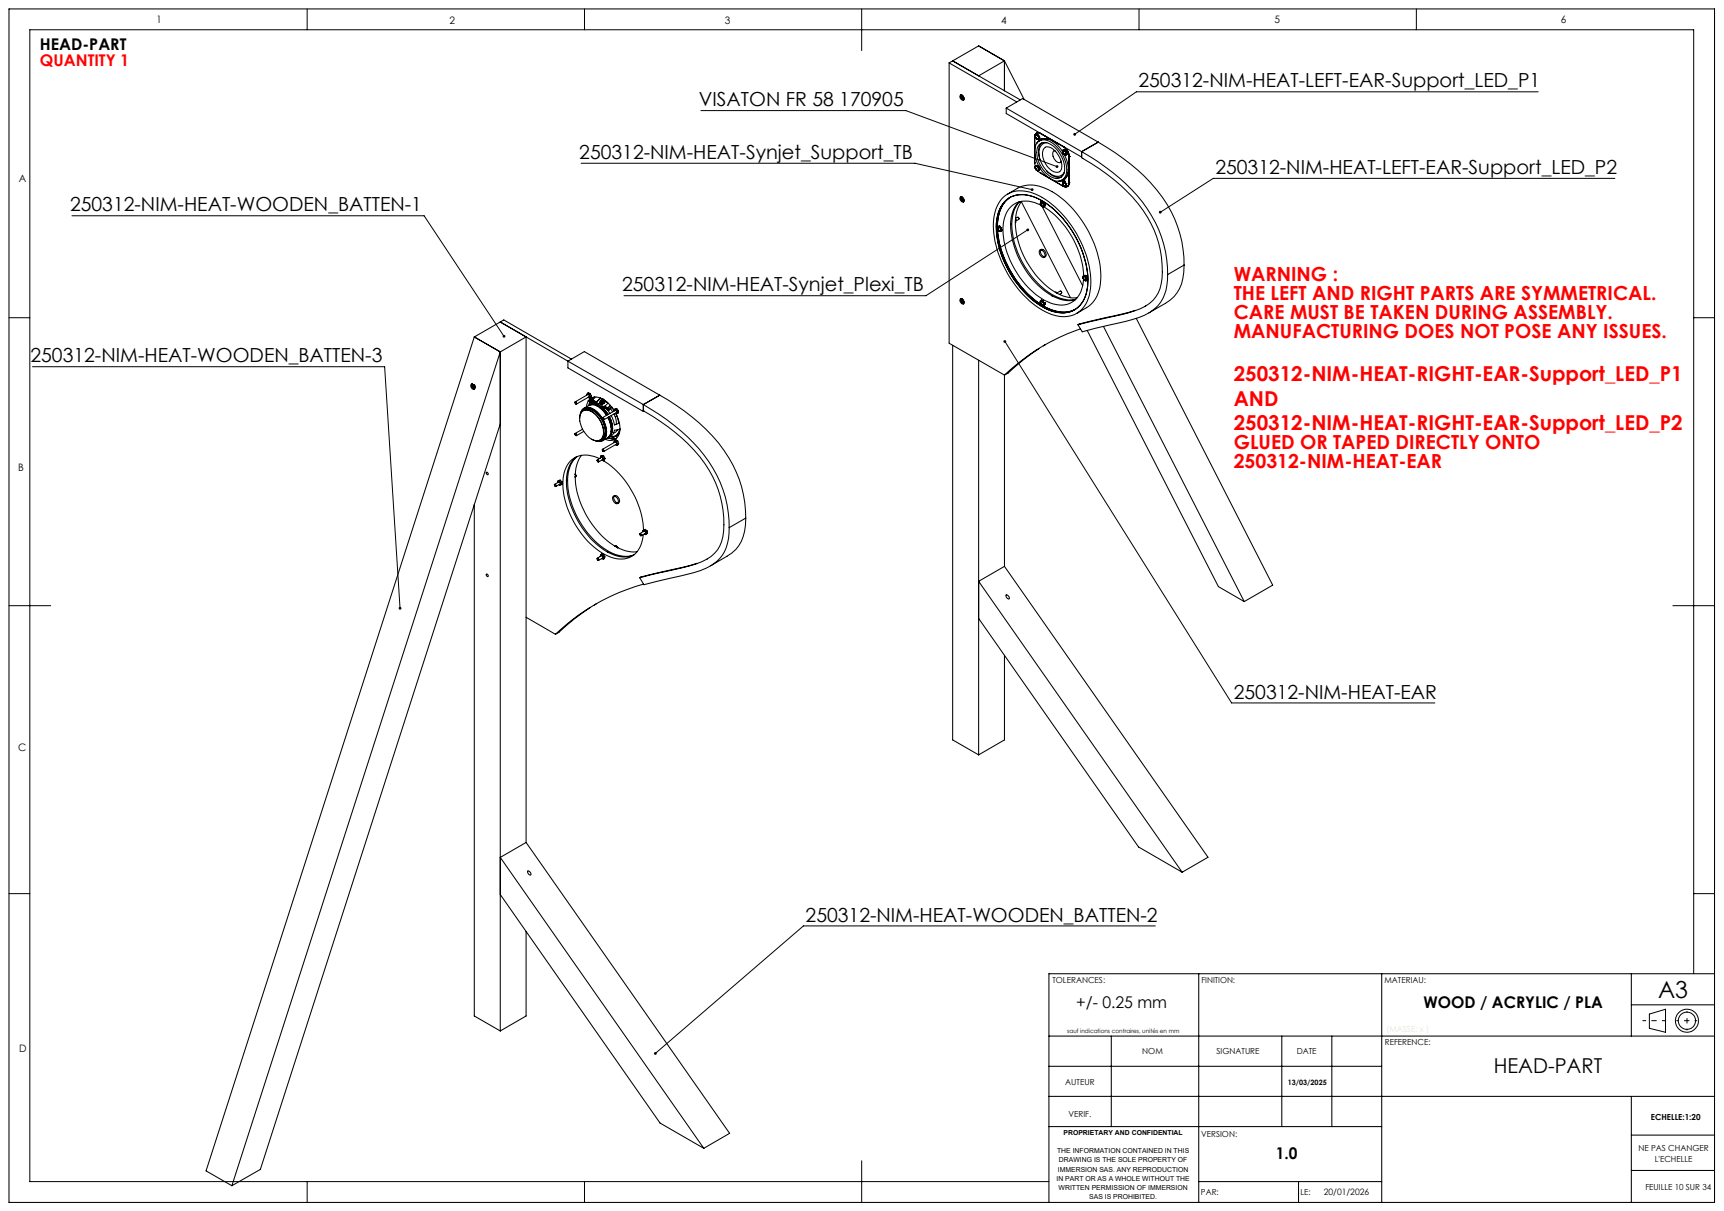
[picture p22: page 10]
VISATON FR 58 170905; WOOD / ACRYLIC / PLA; FEUILLE 10 SUR 34; (MASSE: x )

250312-NIM-HEAT-LEFT-EAR-Support_LED_P1

250312-NIM-HEAT-LEFT-EAR-Support_LED_P2

WARNING :
THE LEFT AND RIGHT PARTS ARE SYMMETRICAL.
CARE MUST BE TAKEN DURING ASSEMBLY.
MANUFACTURING DOES NOT POSE ANY ISSUES.
250312-NIM-HEAT-RIGHT-EAR-Support_LED_P1
AND
250312-NIM-HEAT-RIGHT-EAR-Support_LED_P2
GLUED OR TAPED DIRECTLY ONTO
250312-NIM-HEAT-EAR

sauf indications contraires, unités en mm

NOM | SIGNATURE | DATE | REFERENCE: HEAD-PART 13/03/2025

AUTEUR

VERIF. | | | | | ECHELLE:1:20

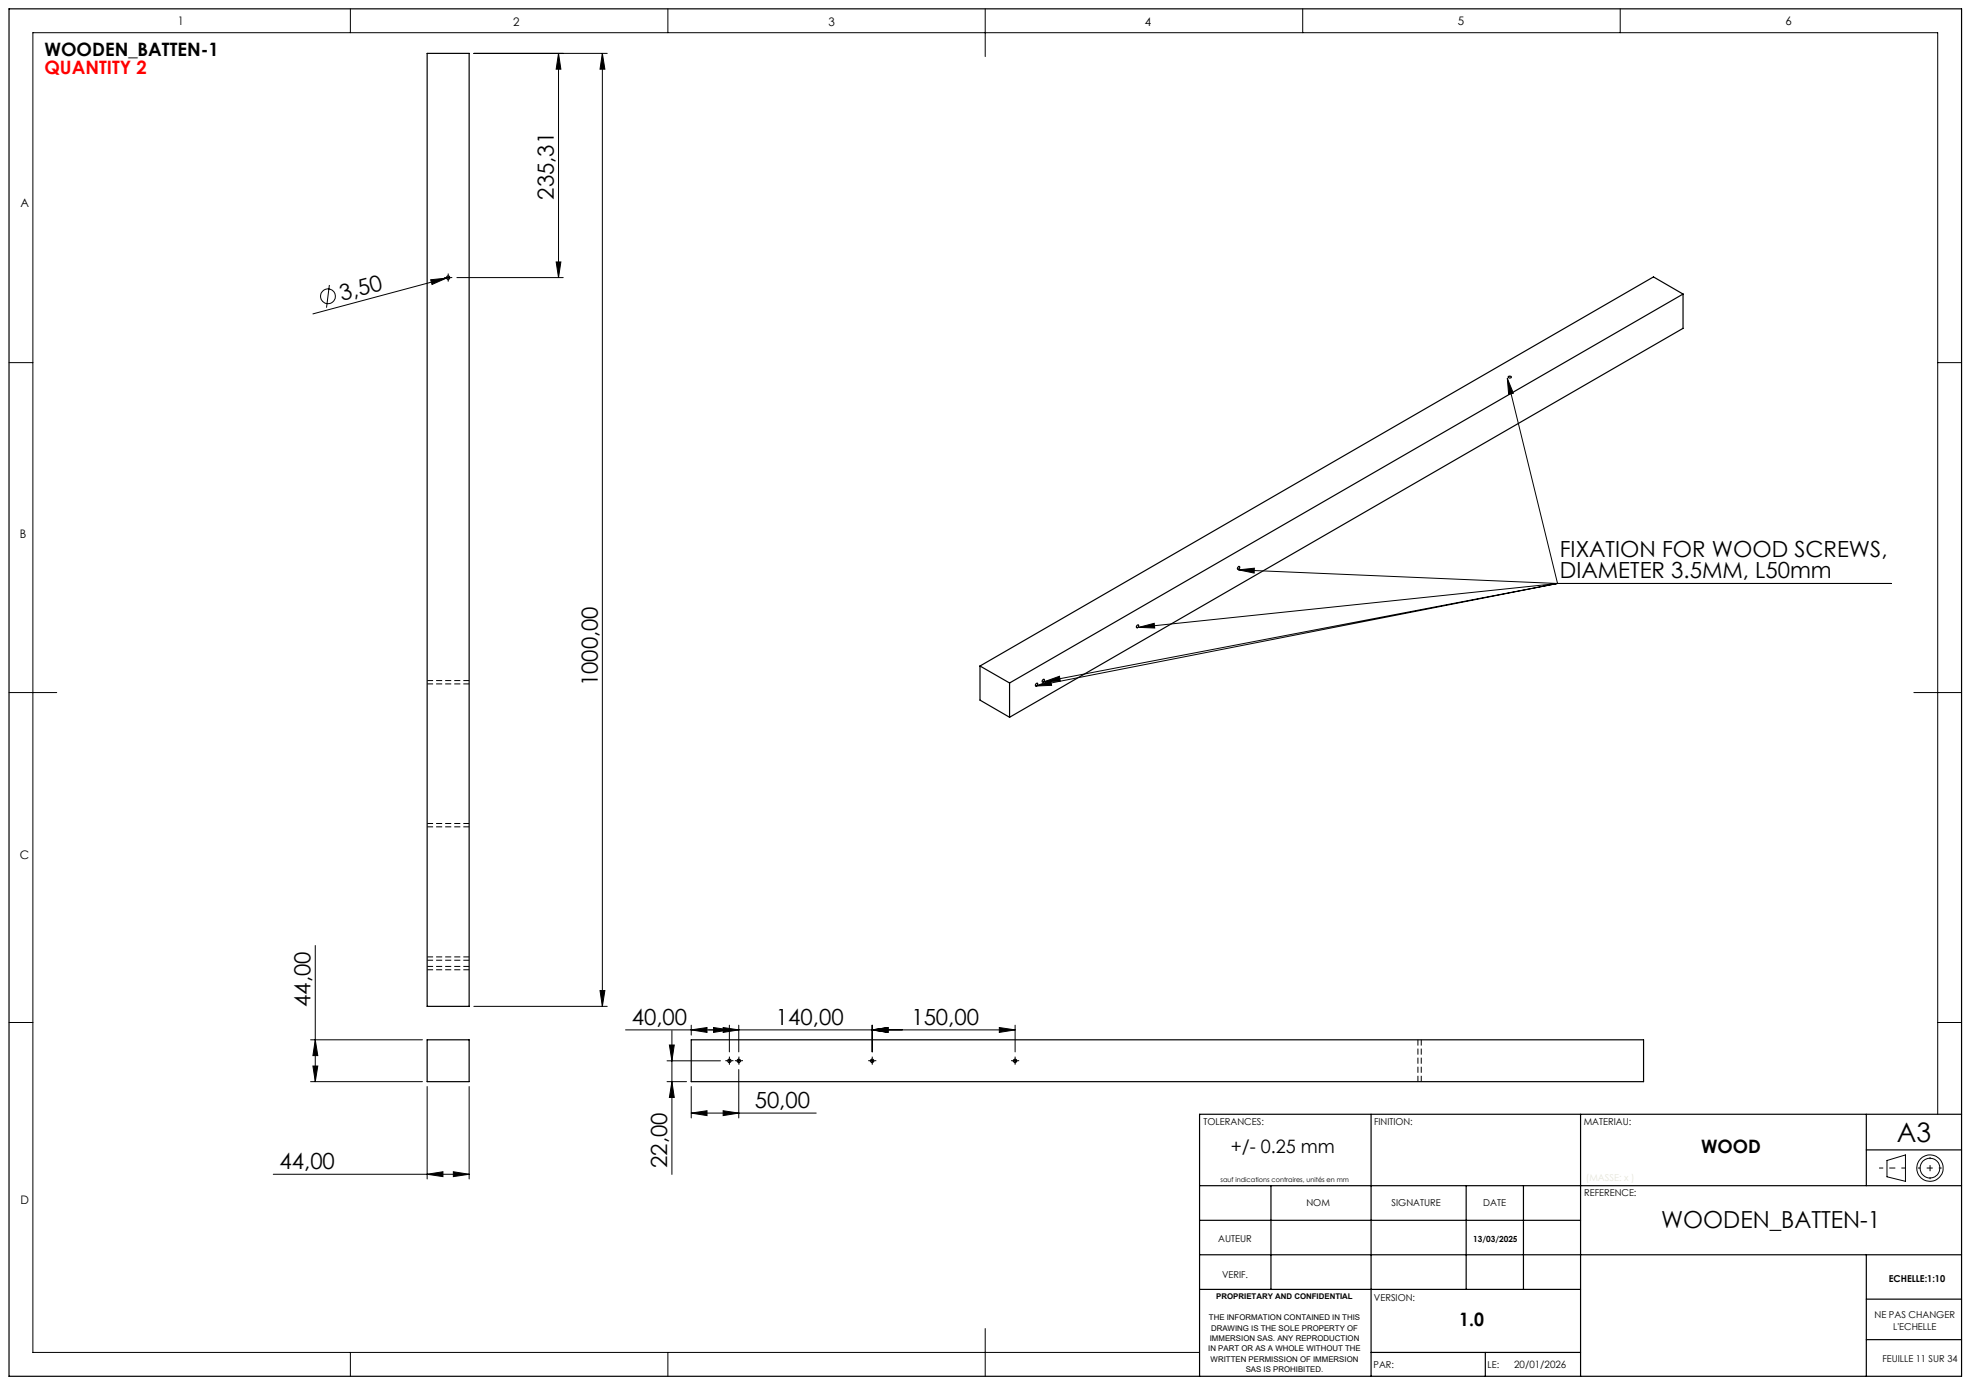
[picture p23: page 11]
FEUILLE 11 SUR 34; (MASSE: x )

FIXATION FOR WOOD SCREWS,
DIAMETER 3.5MM, L50mm

sauf indications contraires, unités en mm

NOM | SIGNATURE | DATE | REFERENCE: WOODEN_BATTEN-1 13/03/2025

AUTEUR

VERIF. | | | | | ECHELLE:1:10

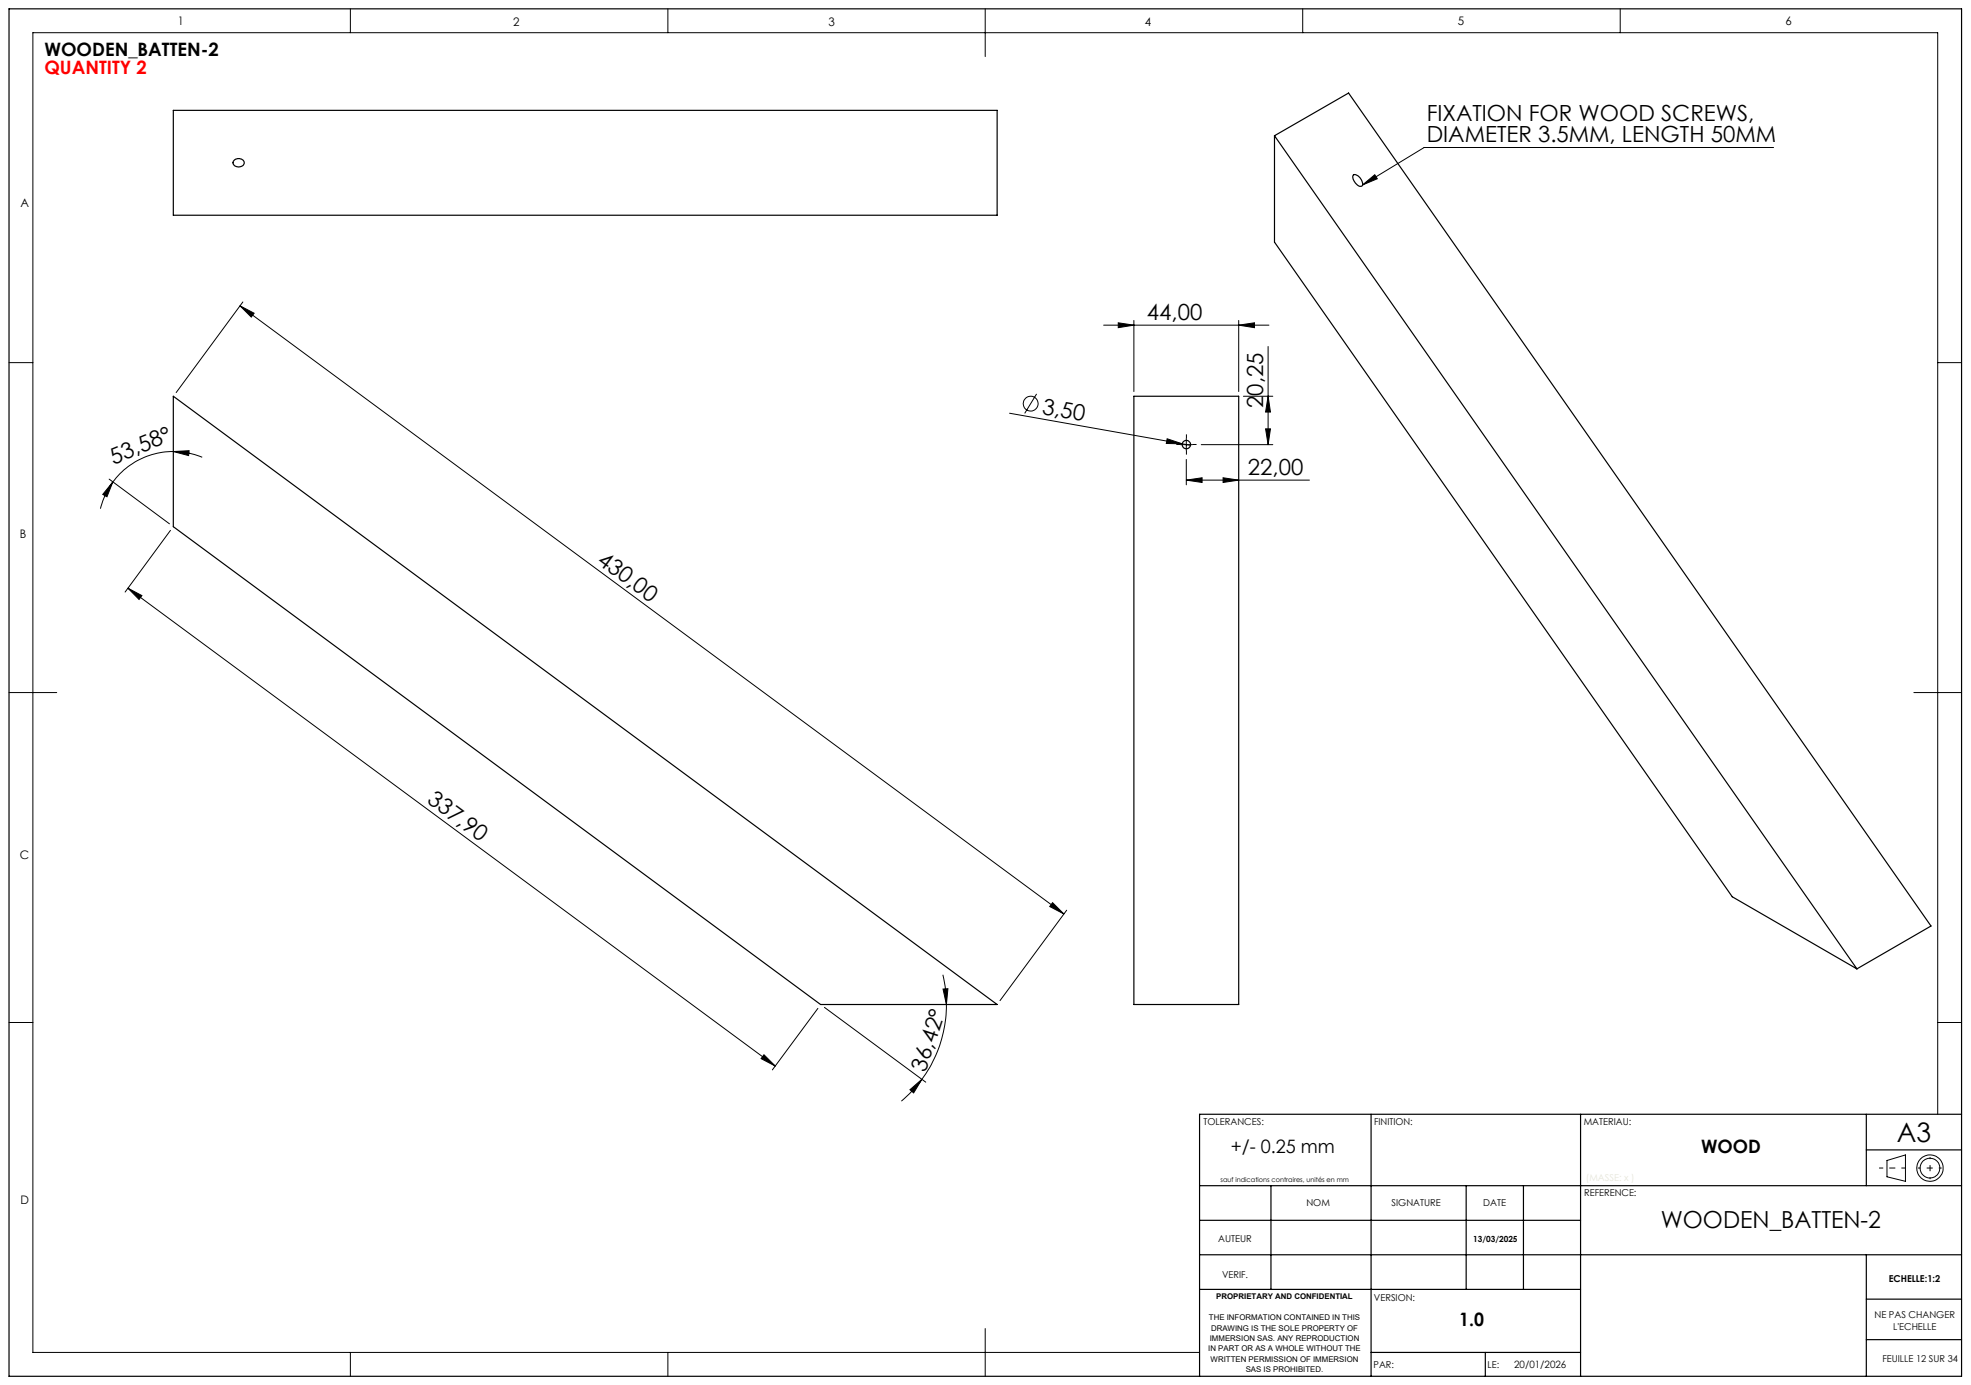
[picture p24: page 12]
FEUILLE 12 SUR 34; (MASSE: x )

FIXATION FOR WOOD SCREWS,
DIAMETER 3.5MM, LENGTH 50MM

sauf indications contraires, unités en mm

NOM | SIGNATURE | DATE | REFERENCE: WOODEN_BATTEN-2 13/03/2025

AUTEUR

VERIF. | | | | | ECHELLE:1:2

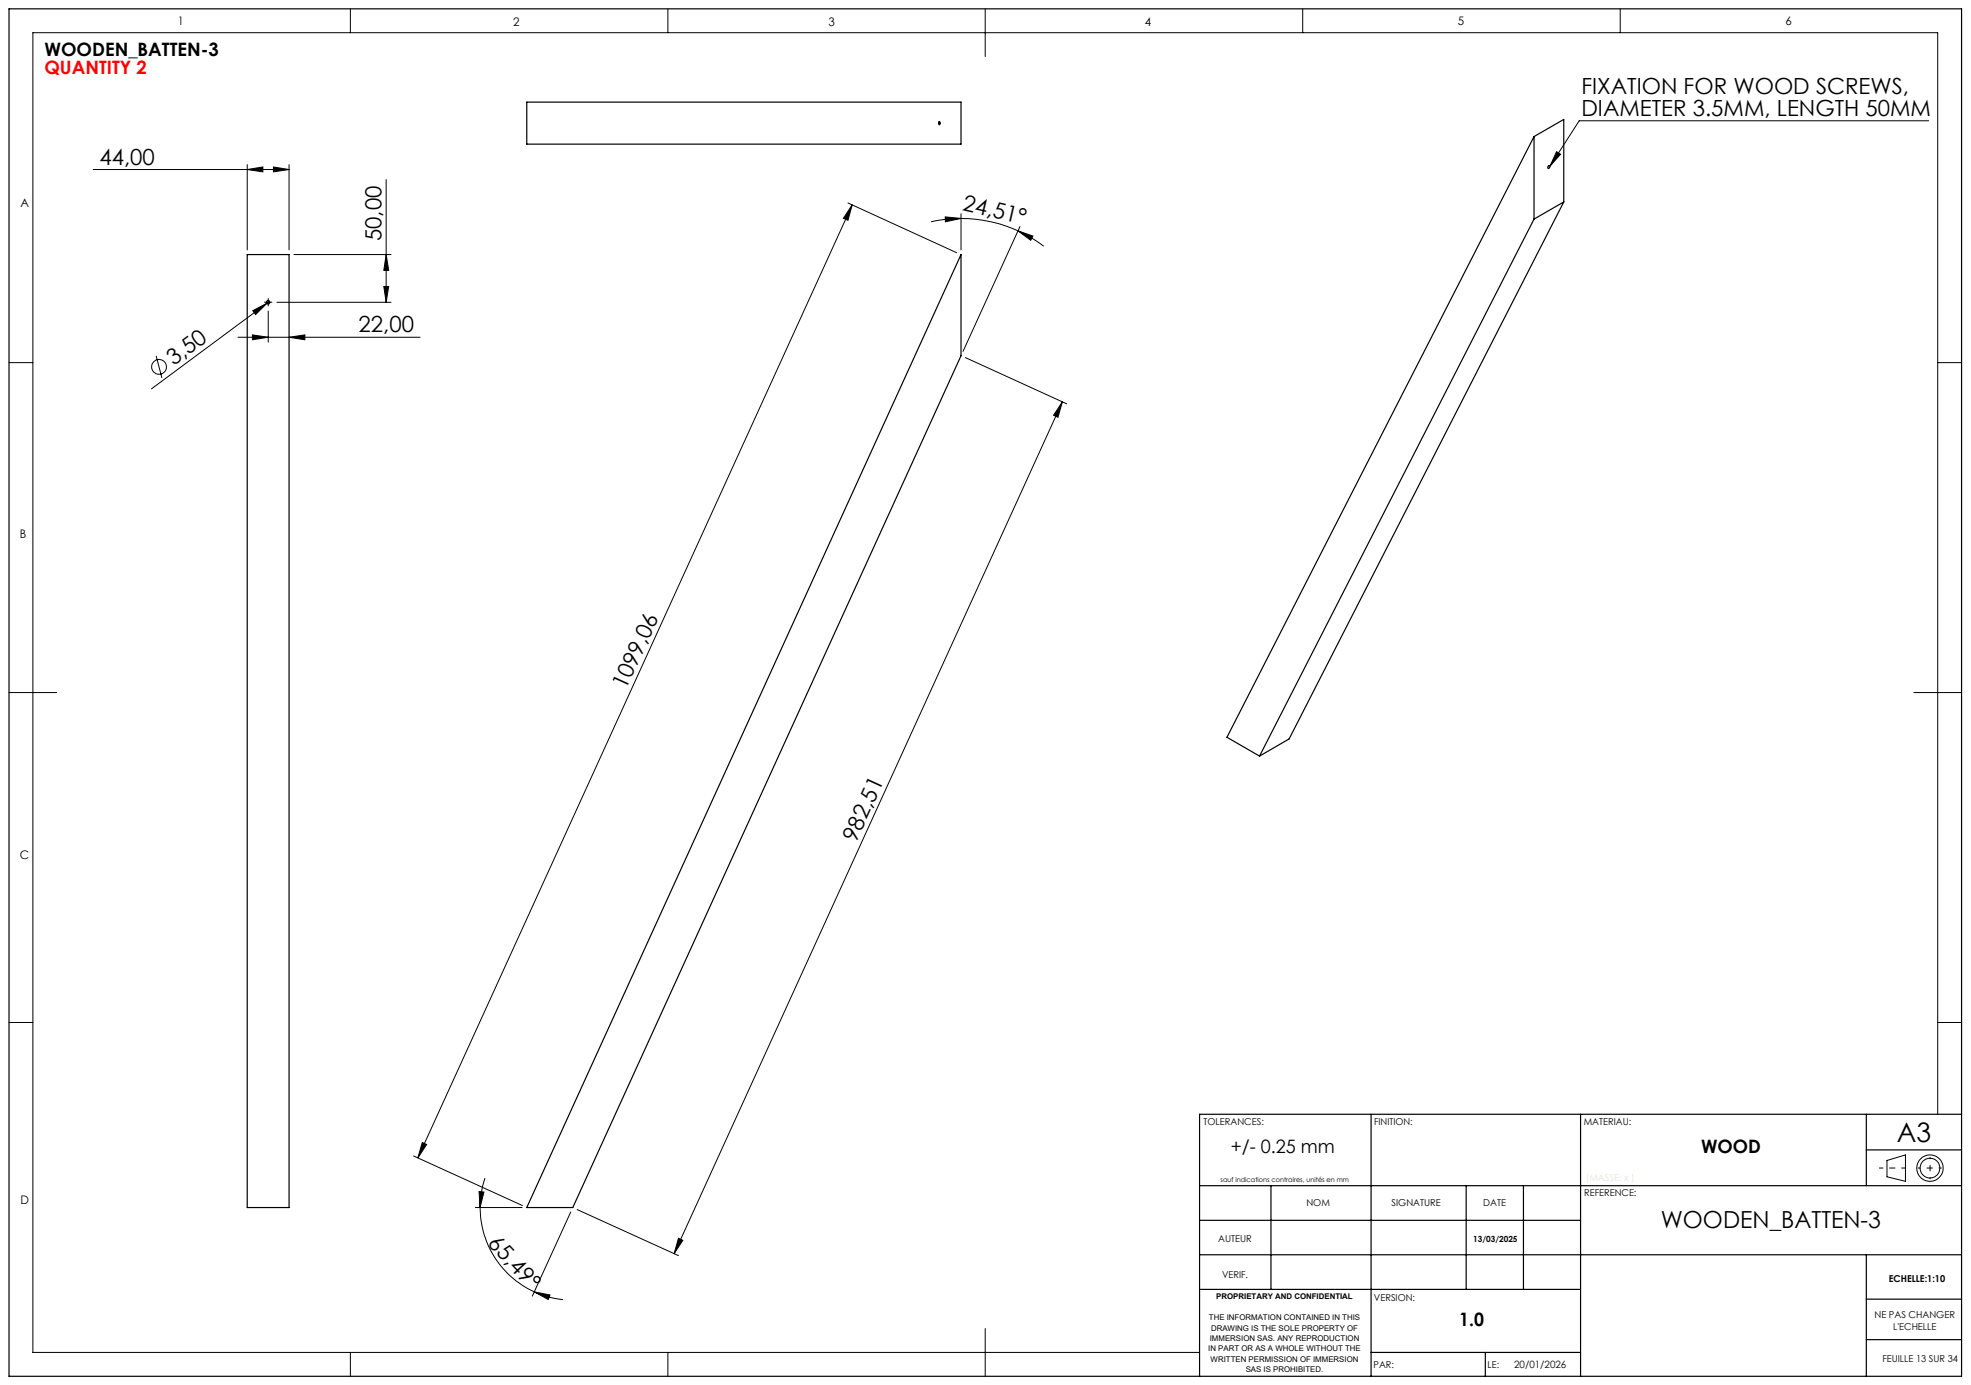
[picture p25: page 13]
FEUILLE 13 SUR 34; (MASSE: x )

FIXATION FOR WOOD SCREWS,
DIAMETER 3.5MM, LENGTH 50MM

sauf indications contraires, unités en mm

NOM | SIGNATURE | DATE | REFERENCE: WOODEN_BATTEN-3 13/03/2025

AUTEUR

VERIF. | | | | | ECHELLE:1:10

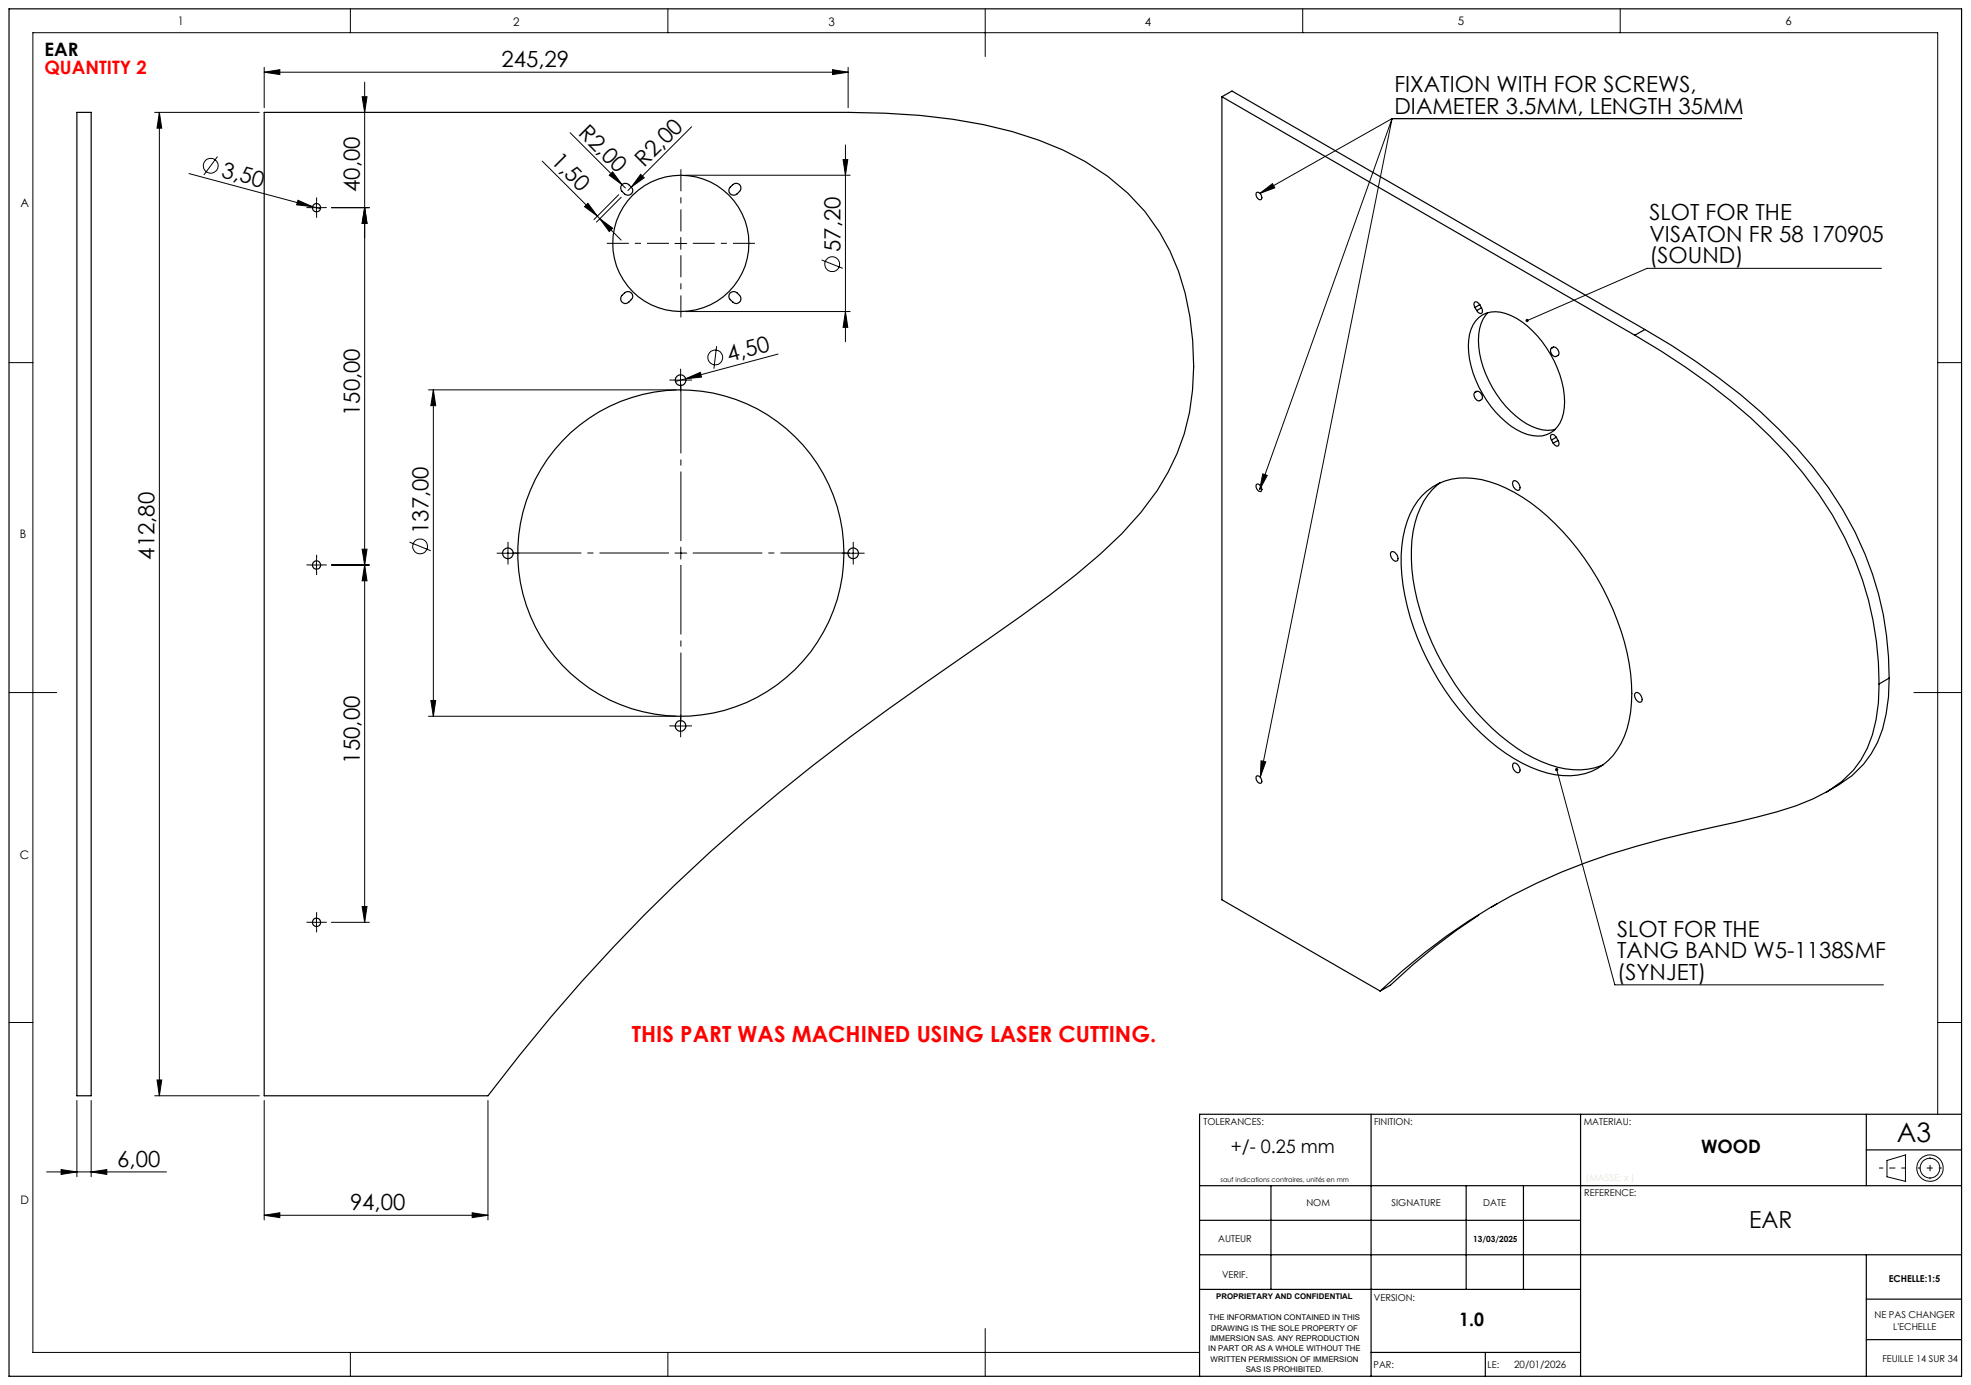
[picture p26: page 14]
FEUILLE 14 SUR 34; (MASSE: x )

FIXATION WITH FOR SCREWS,
DIAMETER 3.5MM, LENGTH 35MM

SLOT FOR THE
VISATON FR 58 170905
(SOUND)

TANG BAND W5-1138SMF
(SYNJET)

THIS PART WAS MACHINED USING LASER CUTTING.

sauf indications contraires, unités en mm

NOM | SIGNATURE | DATE | REFERENCE: EAR 13/03/2025

AUTEUR

VERIF. | | | | | ECHELLE:1:5

FEUILLE 15 SUR 34; (MASSE: x )

THIS PART WAS MANUFACTURED USING A 3D PRINTER.
THE STL FILES FOR PRINTING ARE INCLUDED IN THE PROVIDED FOLDER.

sauf indications contraires, unités en mm

NOM | SIGNATURE | DATE | REFERENCE: LEFT-EAR-Support_LED_P1 13/03/2025

AUTEUR

VERIF. | | | | | ECHELLE:1:1
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
